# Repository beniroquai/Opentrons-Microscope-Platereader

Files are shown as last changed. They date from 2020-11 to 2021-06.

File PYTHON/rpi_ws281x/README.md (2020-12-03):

rpi_ws281x
==========

Userspace Raspberry Pi library for controlling WS281X LEDs.
This includes WS2812 and SK6812RGB RGB LEDs
Preliminary support is now included for SK6812RGBW LEDs (yes, RGB + W)
The LEDs can be controlled by either the PWM (2 independent channels)
or PCM controller (1 channel) or the SPI interface (1 channel).

### Bindings:

Language-specific bindings for rpi_ws281x are available in:

* Python - https://github.com/rpi-ws281x/rpi-ws281x-python
* Rust - https://github.com/rpi-ws281x/rpi-ws281x-rust
* Powershell - https://github.com/rpi-ws281x/rpi-ws281x-powershell
* Java - https://github.com/rpi-ws281x/rpi-ws281x-java
* CSharp - https://github.com/rpi-ws281x/rpi-ws281x-csharp
* Go - https://github.com/rpi-ws281x/rpi-ws281x-go

### Background:

The BCM2835 in the Raspberry Pi has both a PWM and a PCM module that
are well suited to driving individually controllable WS281X LEDs.
Using the DMA, PWM or PCM FIFO, and serial mode in the PWM, it's
possible to control almost any number of WS281X LEDs in a chain connected
to the appropriate output pin.
For SPI the Raspbian spidev driver is used (`/dev/spidev0.0`).
This library and test program set the clock rate to 3X the desired output
frequency and creates a bit pattern in RAM from an array of colors where
each bit is represented by 3 bits as follows.

    Bit 1 - 1 1 0
    Bit 0 - 1 0 0

### GPIO Usage:

The GPIOs that can be used are limited by the hardware of the Pi and will
vary based on the method used to drive them (PWM, PCM or SPI).
Beware that the GPIO numbers are not the same as the physical pin numbers
on the header.

PWM:
```
        PWM0, which can be set to use GPIOs 12, 18, 40, and 52.
        Only 12 (pin 32) and 18 (pin 12) are available on the B+/2B/3B

        PWM1 which can be set to use GPIOs 13, 19, 41, 45 and 53.
        Only 13 is available on the B+/2B/PiZero/3B, on pin 33
```

PCM:
```
        PCM_DOUT, which can be set to use GPIOs 21 and 31.
        Only 21 is available on the B+/2B/PiZero/3B, on pin 40.
```

SPI:
```
        SPI0-MOSI is available on GPIOs 10 and 38.
        Only GPIO 10 is available on all models.
        See also note for RPi 3 below.
```

### Power and voltage requirements

WS281X LEDs are generally driven at 5V. Depending on your actual
LED model and data line length you might be able to successfully drive
the data input with 3.3V. However in the general case you probably
want to use a level shifter to convert from the Raspberry Pi GPIO/PWM to 5V.

It is also possible to run the LEDs from a 3.3V - 3.6V power source, and
connect the GPIO directly at a cost of brightness, but this isn't
recommended.

The test program is designed to drive a 8x8 grid of LEDs e.g.from
Adafruit (http://www.adafruit.com/products/1487) or Pimoroni
(https://shop.pimoroni.com/products/unicorn-hat).
Please see the Adafruit and Pimoroni websites for more information.

Know what you're doing with the hardware and electricity.  I take no
reponsibility for damage, harm, or mistakes.

### Build:

#### Build with SCons:

- Install Scons (on raspbian, `apt-get install scons`).
- Make sure to adjust the parameters in main.c to suit your hardware.
  - Signal rate (400kHz to 800kHz).  Default 800kHz.
  - ledstring.invert=1 if using a inverting level shifter.
  - Width and height of LED matrix (height=1 for LED string).
- Type `scons` from inside the source directory.

#### Build and install with CMake:

- Install CMake
- Configure your build:

  For example:
  ```
  mkdir build
  cd build
  cmake -D BUILD_SHARED=OFF -D BUILD_TEST=ON ..
  ```
  See also for available options in `CMakeLists.txt`.
- Type `cmake --build .` to build
- To install built binaries and headers into your system type:
  ```
  sudo make install
  ```

### Running:

- Type `sudo ./test` (default uses PWM channel 0).
- That's it.  You should see a moving rainbow scroll across the
  display.
- More options are available, `./test -h` should show them:
```
./test version 1.1.0
Usage: ./test
-h (--help)    - this information
-s (--strip)   - strip type - rgb, grb, gbr, rgbw
-x (--width)   - matrix width (default 8)
-y (--height)  - matrix height (default 8)
-d (--dma)     - dma channel to use (default 10)
-g (--gpio)    - GPIO to use
                 If omitted, default is 18 (PWM0)
-i (--invert)  - invert pin output (pulse LOW)
-c (--clear)   - clear matrix on exit.
-v (--version) - version information
```

### Important warning about DMA channels

You must make sure that the DMA channel you choose to use for the LEDs is not [already in use](https://www.raspberrypi.org/forums/viewtopic.php?p=609380#p609380) by the operating system.

For example, **using DMA channel 5 [will cause](https://github.com/jgarff/rpi_ws281x/issues/224) filesystem corruption** on the Raspberry Pi 3 Model B.

The default DMA channel (10) should be safe for the Raspberry Pi 3 Model B, but this may change in future software releases.

### Limitations:

#### PWM

Since this library and the onboard Raspberry Pi audio
both use the PWM, they cannot be used together.  You will need to
blacklist the Broadcom audio kernel module by creating a file
`/etc/modprobe.d/snd-blacklist.conf` with

    blacklist snd_bcm2835

If the audio device is still loading after blacklisting, you may also
need to comment it out in the /etc/modules file.

On headless systems you may also need to force audio through hdmi
Edit config.txt and add:

    hdmi_force_hotplug=1
    hdmi_force_edid_audio=1

A reboot is required for this change to take effect

Some distributions use audio by default, even if nothing is being played.
If audio is needed, you can use a USB audio device instead.

#### PCM

When using PCM you cannot use digital audio devices which use I2S since I2S
uses the PCM hardware, but you can use analog audio.

#### SPI

When using SPI the led string is the only device which can be connected to
the SPI bus. Both digital (I2S/PCM) and analog (PWM) audio can be used.

Many distributions have a maximum SPI transfer of 4096 bytes. This can be
changed in `/boot/cmdline.txt` by appending
```
    spidev.bufsiz=32768
```

On an RPi 3 you have to change the GPU core frequency to 250 MHz, otherwise
the SPI clock has the wrong frequency.

Do this by adding the following line to /boot/config.txt and reboot:

```
    core_freq=250
```

On an RPi 4 you must set a fixed frequency to avoid the idle CPU scaling changing the SPI frequency and breaking the ws281x timings:

Do this by adding the following lines to /boot/config.txt and reboot:

```
    core_freq=500
    core_freq_min=500
```

SPI requires you to be in the `gpio` group if you wish to control your LEDs
without root.

### Comparison PWM/PCM/SPI

Both PWM and PCM use DMA transfer to output the control signal for the LEDs.
The max size of a DMA transfer is 65536 bytes. Since each LED needs 12 bytes
(4 colors, 8 symbols per color, 3 bits per symbol) this means you can
control approximately 5400 LEDs for a single strand in PCM and 2700 LEDs per string
for PWM (Only PWM can control 2 independent strings simultaneously)
SPI uses the SPI device driver in the kernel. For transfers larger than
96 bytes the kernel driver also uses DMA.
Of course there are practical limits on power and signal quality. These will
be more constraining in practice than the theoretical limits above.

When controlling a LED string of 240 LEDs the CPU load on the original Pi 2 (BCM2836) are:
  PWM  5%
  PCM  5%
  SPI  1%

### Usage:

The API is very simple.  Make sure to create and initialize the `ws2811_t`
structure as seen in [`main.c`](main.c).  From there it can be initialized
by calling `ws2811_init()`.  LEDs are changed by modifying the color in
the `.led[index]` array and calling `ws2811_render()`.
The rest is handled by the library, which either creates the DMA memory and
starts the DMA for PWM and PCM or prepares the SPI transfer buffer and sends
it out on the MISO pin.

Make sure to hook a signal handler for SIGKILL to do cleanup.  From the
handler make sure to call `ws2811_fini()`.  It'll make sure that the DMA
is finished before program execution stops and cleans up after itself.

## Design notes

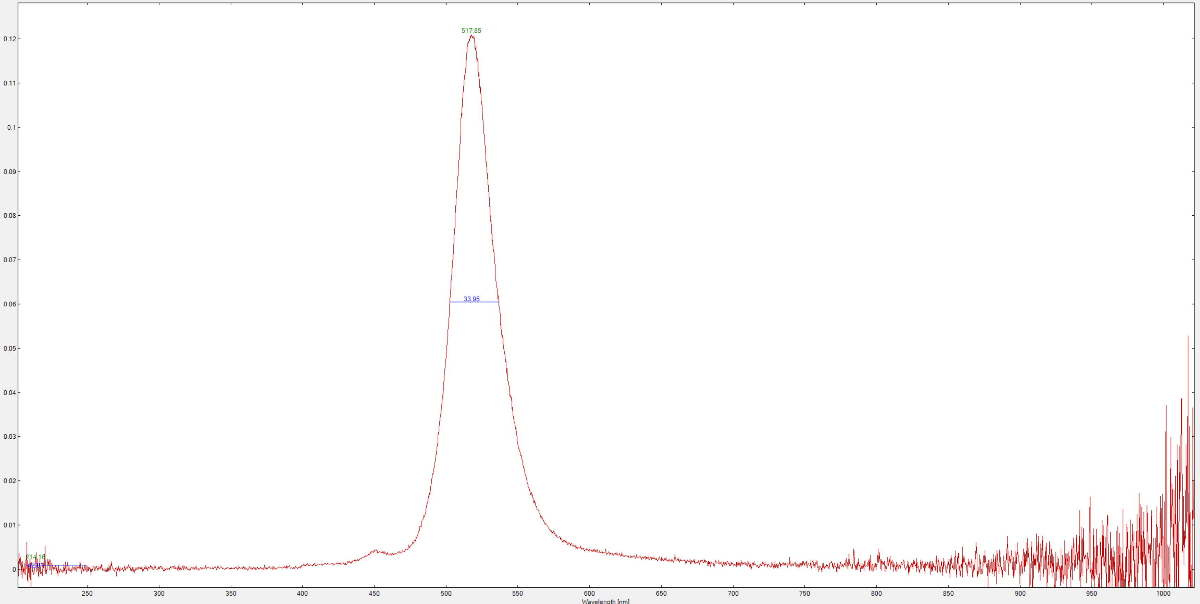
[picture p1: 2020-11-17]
IMAGES/Spectrometer_Neopixel_ring_onlyGreen.PNG

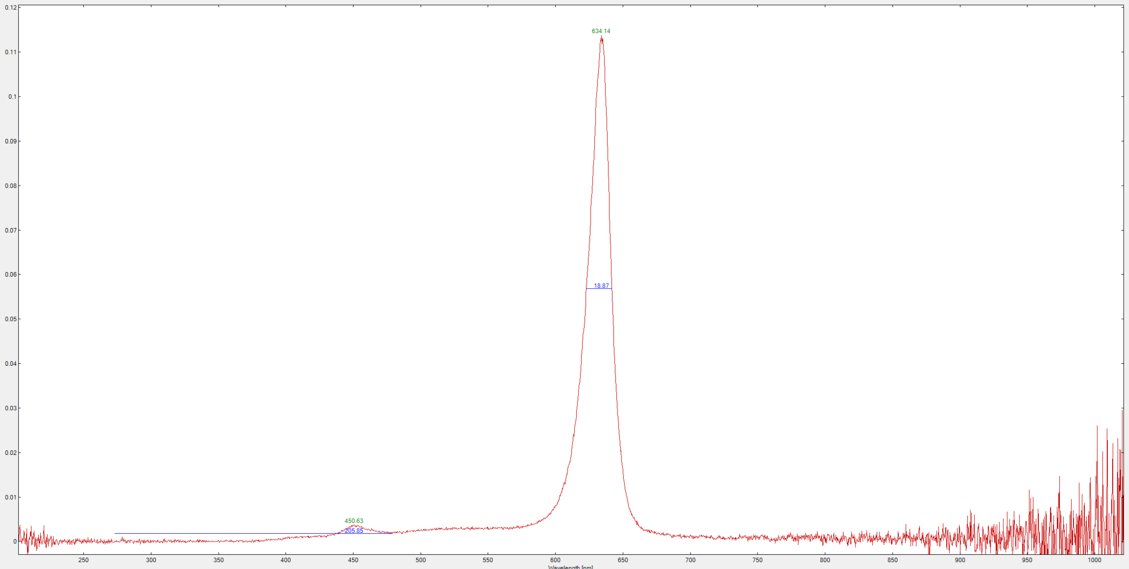
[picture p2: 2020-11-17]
IMAGES/Spectrometer_Neopixel_ring_onlyRed.PNG

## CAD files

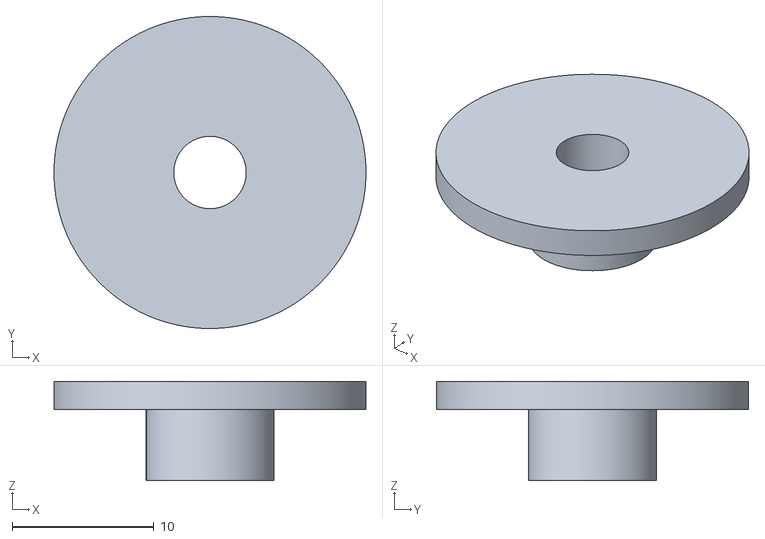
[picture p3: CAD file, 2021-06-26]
INVENTOR/13_Fluorescence_Arm_LEDholder.stl
22.0 x 22.0 x 7.00

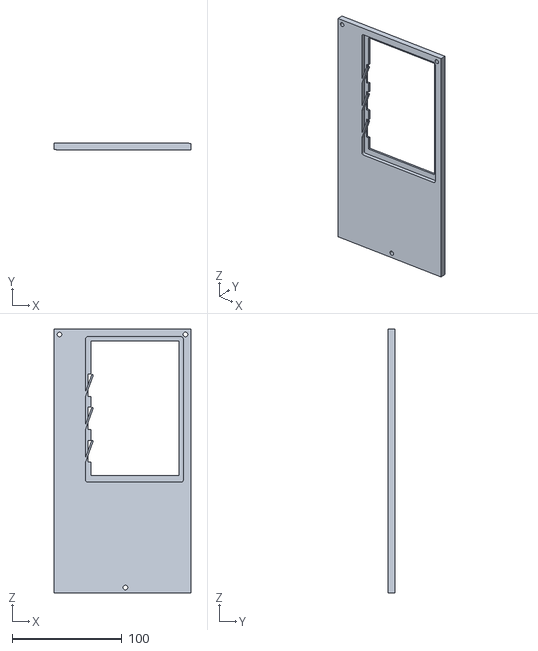
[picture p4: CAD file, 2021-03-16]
STL/Opentronscope_04_OPENTRONS_Microscope_wellplate_base.stl
125.0 x 6.07 x 241.0

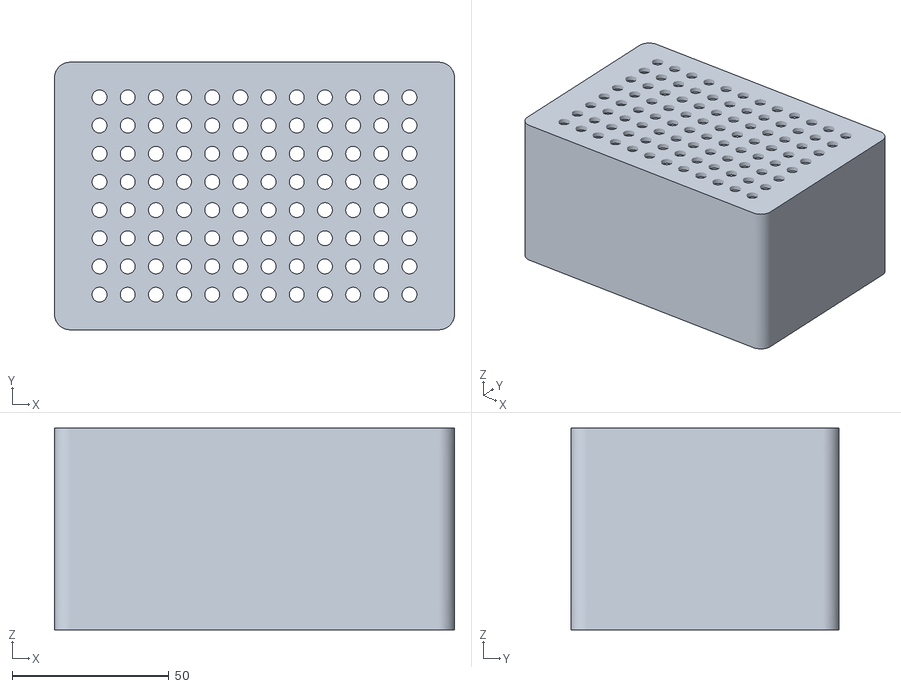
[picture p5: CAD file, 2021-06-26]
INVENTOR/00_Rack_Eppendorf_96_200mul_tips.stl
127.8 x 85.5 x 64.5

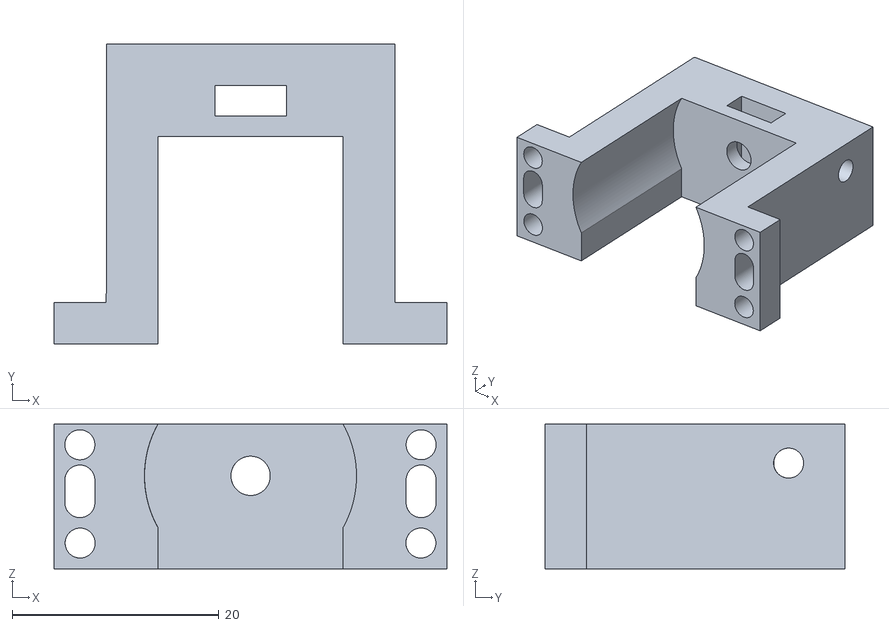
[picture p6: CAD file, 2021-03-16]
STL/Opentronscope_opentrons_Gearbox.stl
38.0 x 29.0 x 14.0

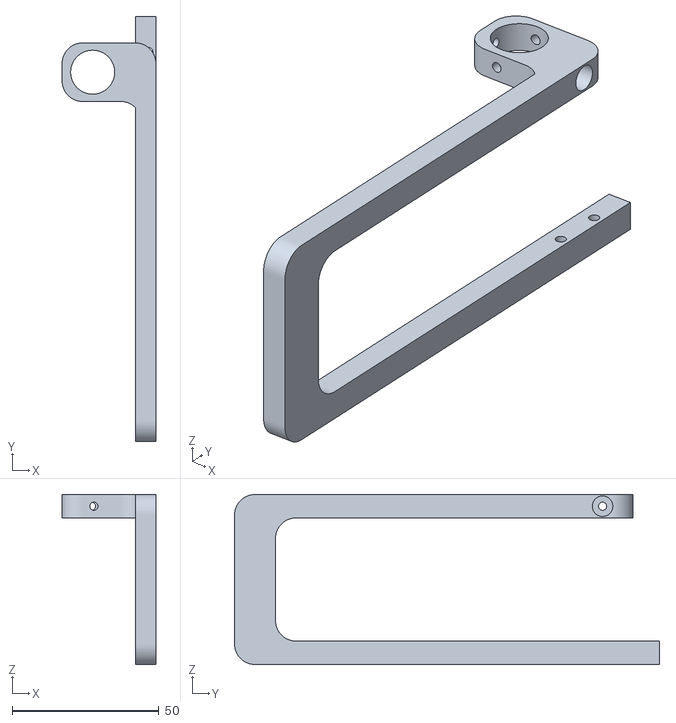
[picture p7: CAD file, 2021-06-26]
INVENTOR/06_Fluorescence_Arm.stl
32.0 x 145.0 x 58.0

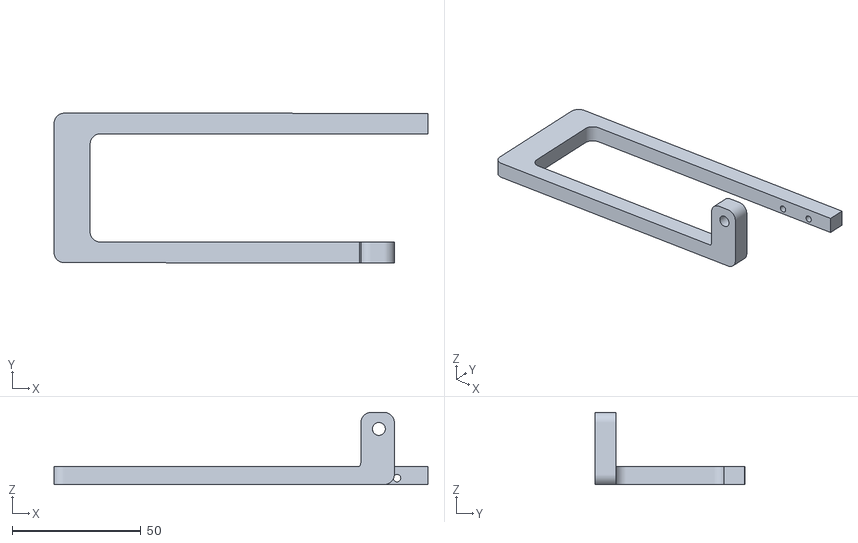
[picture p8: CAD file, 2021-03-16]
STL/Opentronscope_06_Fluorescence_Arm.stl
145.0 x 58.1 x 28.0

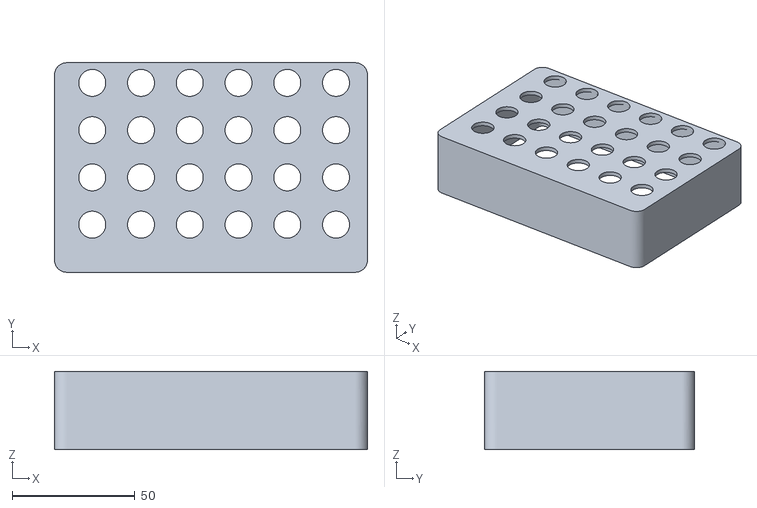
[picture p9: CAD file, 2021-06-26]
INVENTOR/00_Rack_Eppendorf_Tubes.stl
127.7 x 85.5 x 32.0

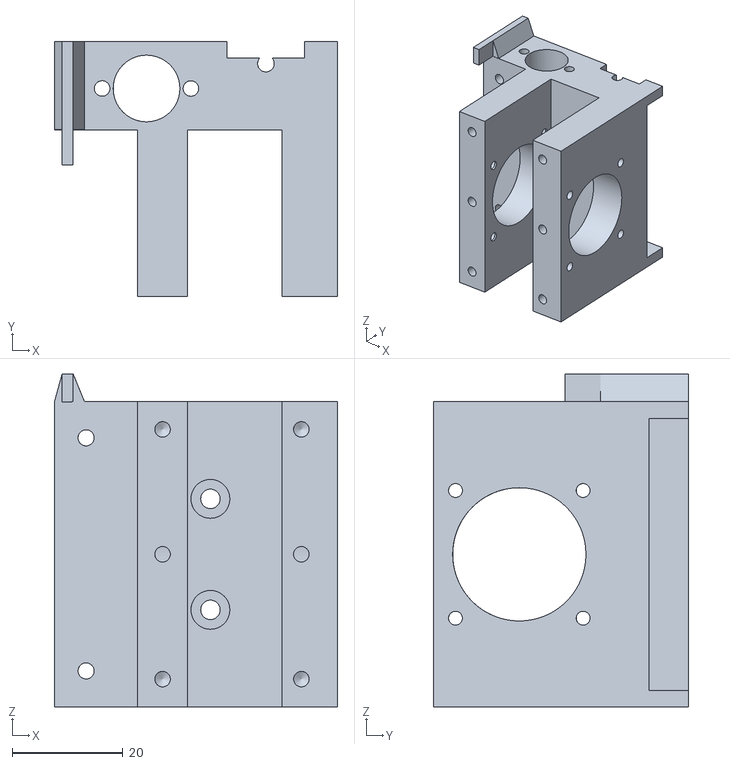
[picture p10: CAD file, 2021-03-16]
STL/Opentronscope_01_Slide_camera_y_v0.stl
51.0 x 46.0 x 60.0

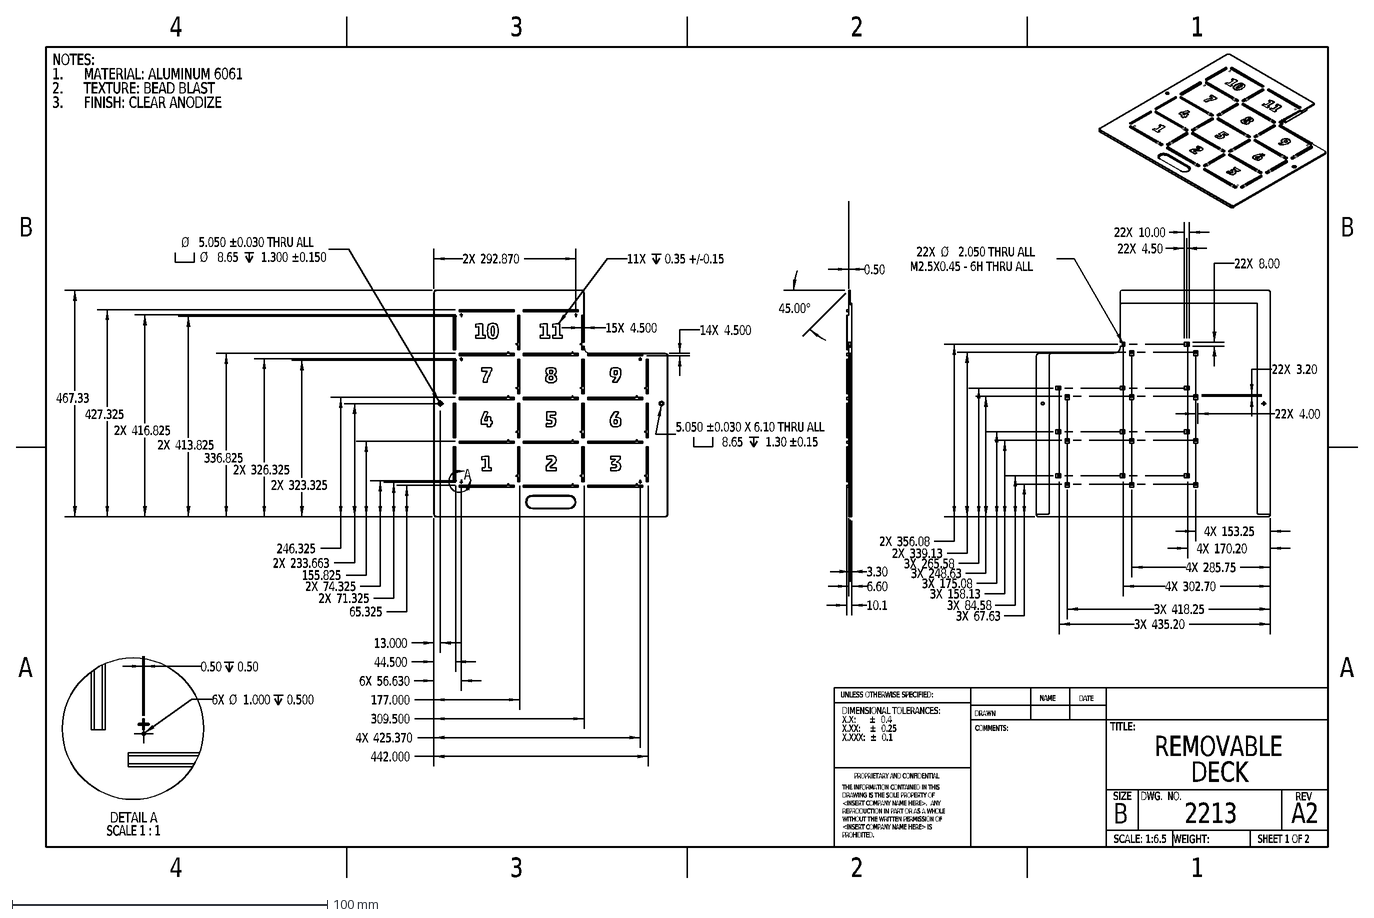
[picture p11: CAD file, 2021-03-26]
INVENTOR/CNC_DECK_RevA2.DXF
NOTES:
MATERIAL: ALUMINUM 6061
1.
TEXTURE: BEAD BLAST
2.
FINISH: CLEAR ANODIZE
3.
REMOVABLE
DECK
A2
2213
SHEET 1 OF 2
UNLESS OTHERWISE SPECIFIED:
SCALE: 1:6.5
WEIGHT:
REV
DWG. NO.
B
SIZE
TITLE:
NAME
DATE
COMMENTS:
DRAWN
PROPRIETARY AND CONFIDENTIAL
THE INFORMATION CONTAINED IN THIS
DRAWING IS THE SOLE PROPERTY OF
<INSERT COMPANY NAME HERE>. ANY
REPRODUCTION IN PART OR AS A WHOLE
WITHOUT THE WRITTEN PERMISSION OF
<INSERT COMPANY NAME HERE> IS
PROHIBITED.
DIMENSIONAL TOLERANCES:
X.X:
±
0.4
X.XX:
0.25
X.XXX:
0.1
A
4
3
2
1
2X
233.663
71.325
65.325
155.825
246.325
336.825
427.325
326.325
416.825
467.33
13.000
44.500
309.500
442.000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

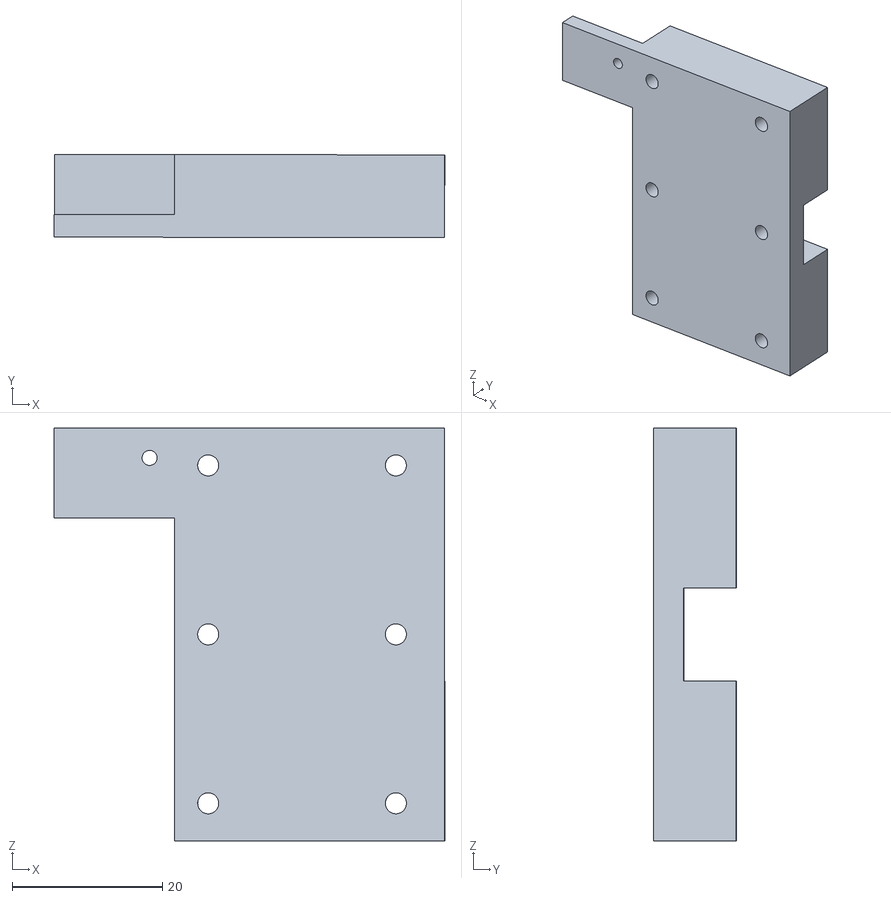
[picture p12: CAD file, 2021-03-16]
STL/Opentronscope_04_Mount_Rail_Fastener.stl
52.0 x 11.0 x 55.0

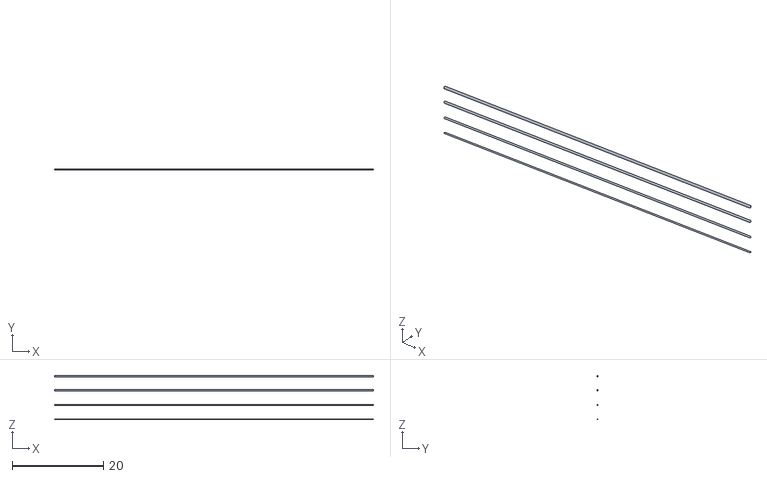
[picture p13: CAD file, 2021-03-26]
INVENTOR/Part1.stl
70.0 x 0.3 x 9.70

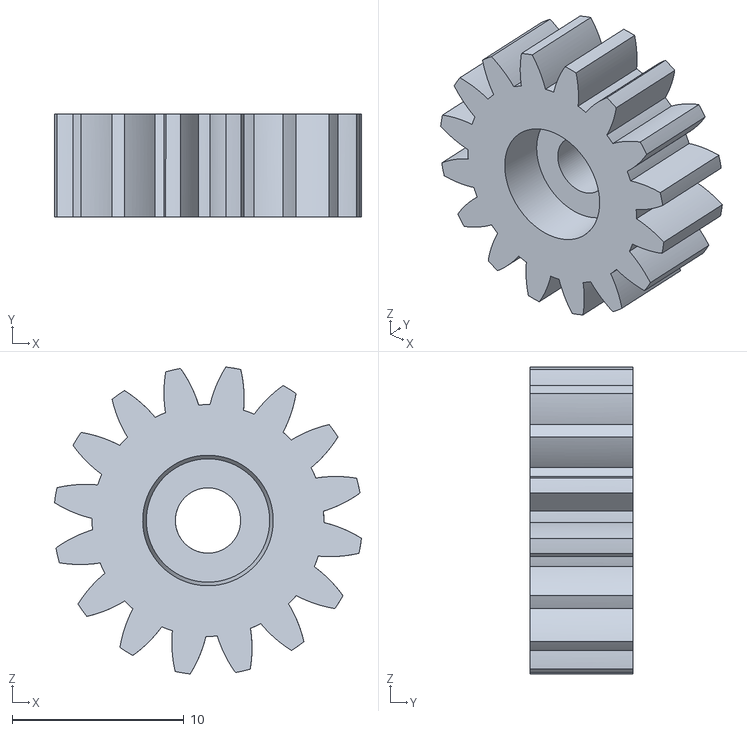
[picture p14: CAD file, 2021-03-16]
STL/Opentronscope_opentrons_gear2.stl
17.9 x 6.01 x 17.9

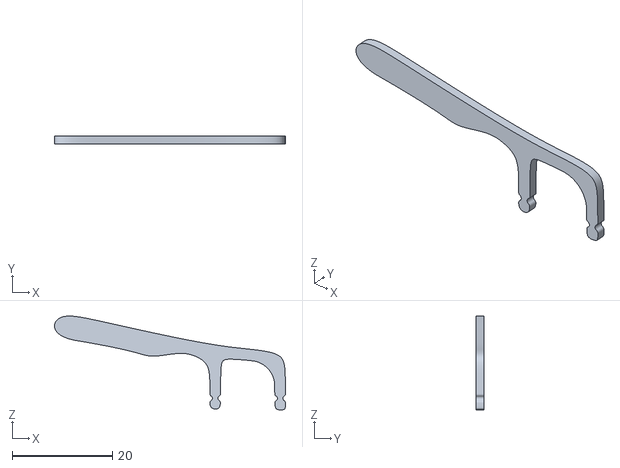
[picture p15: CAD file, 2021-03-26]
INVENTOR/toothpick.stl
46.1 x 1.50 x 18.7

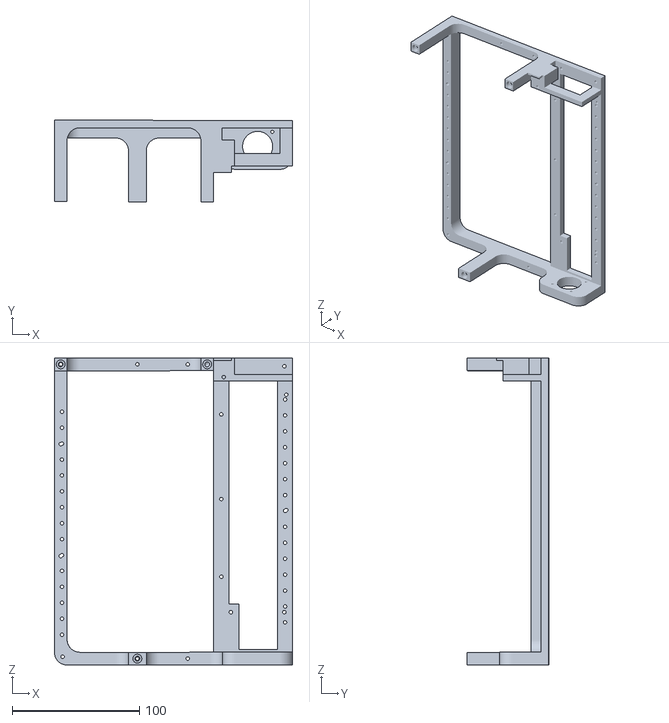
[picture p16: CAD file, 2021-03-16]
STL/Opentronscope_02_Opentrons_Microscope_Base_v0.stl
187.1 x 64.1 x 241.0

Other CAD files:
INVENTOR/09_Lid_Electronics.stl
STL/Opentronscope_01_Slide_camera_v1.stl
INVENTOR/09_Opentrons_Microscope_Baseplate.stl
STL/Opentronscope_01_Slide_camera_flexure_v1.stl
INVENTOR/00_Beampath_Autofocus _2.ipt
INVENTOR/00_COMAR_Mirror_10mm.ipt
INVENTOR/00_ESP32_Camera_only.ipt
INVENTOR/00_Endstop.ipt
INVENTOR/00_IGUS_Drylin_RJ4JP-01-06.ipt
INVENTOR/00_IR_Laserdiode.ipt
INVENTOR/00_LED_neopixel_single.ipt
INVENTOR/00_MGN12 LINEAR GUIDE RAIL, CONFIGURABLE.ipt
INVENTOR/00_MGN12C, LINEAR GUIDE BLOCK.ipt
INVENTOR/00_MGN12H, LINEAR GUIDE BLOCK.ipt
INVENTOR/00_NEMA11.iam
INVENTOR/00_Rack_Eppendorf_96_200mul_tips.ipt
INVENTOR/00_Rack_Eppendorf_Tubes.ipt
INVENTOR/00_RasPi_Camera.ipt
INVENTOR/00_Raspberry_Pi_3.iam
INVENTOR/00_Thorlabs_Rod_200mm.ipt
INVENTOR/00_coverslip.ipt
INVENTOR/00_endstop_optical.ipt
INVENTOR/00_endstop_optical.stp
INVENTOR/00_lens_10mm.ipt
INVENTOR/00_objectivelens_10x.ipt
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

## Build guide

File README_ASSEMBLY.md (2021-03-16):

# Assemble the XY-stage 

These are more-less all components you would need for the XY-stage to operate. The Z-focus assembly is explained below

### All ingredients

<p align="left">
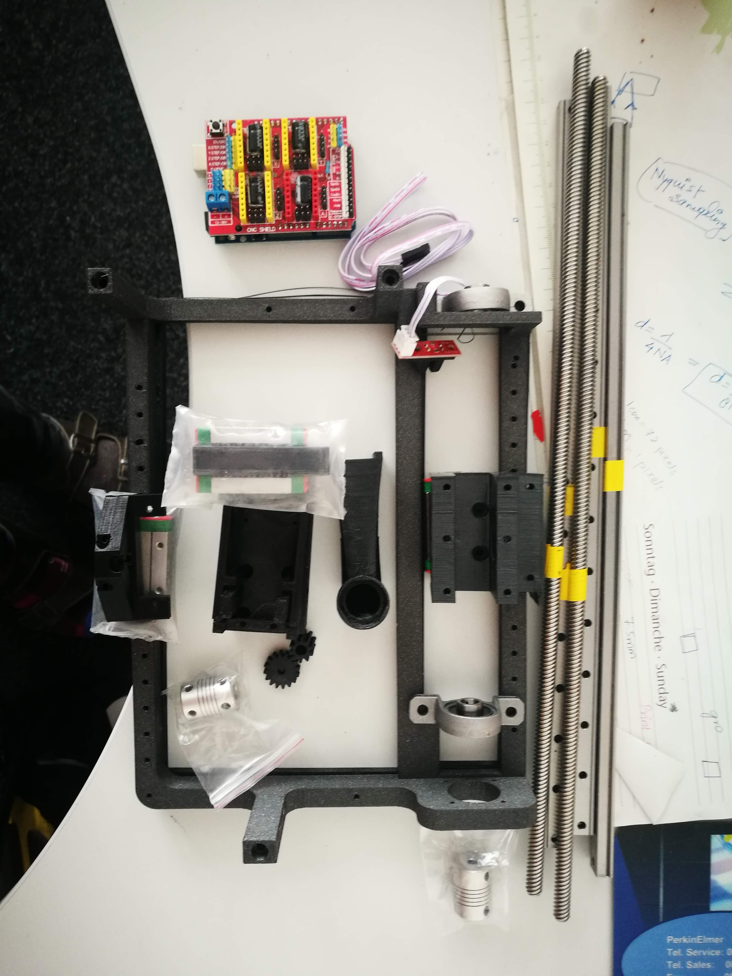
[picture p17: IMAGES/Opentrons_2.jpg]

</p>

### Prepare the metal parts / slides

Cut! 

<p align="left">
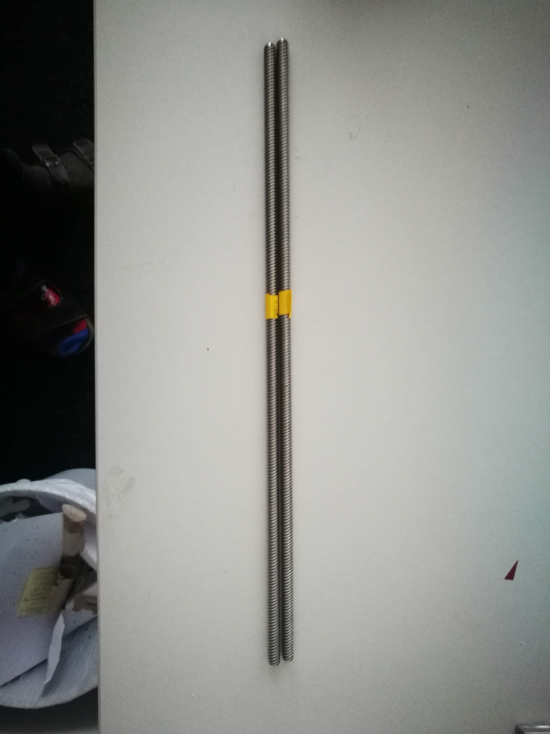
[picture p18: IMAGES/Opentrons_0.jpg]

</p>

<p align="left">
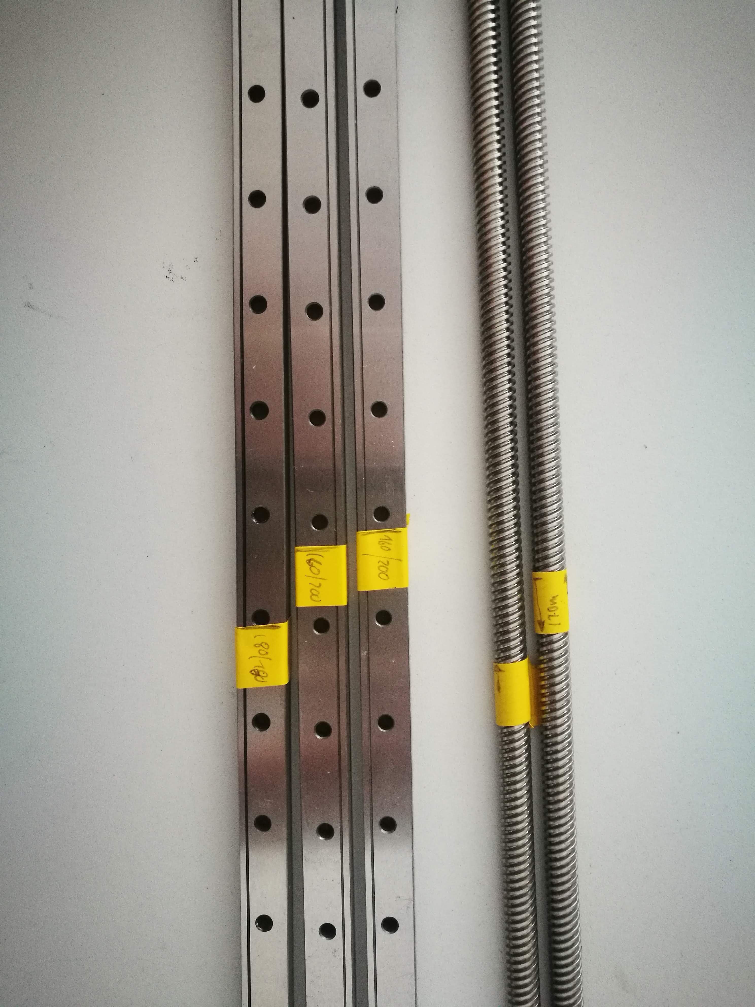
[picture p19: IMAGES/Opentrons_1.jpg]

</p>

### Assembling the optics module

<p align="left">
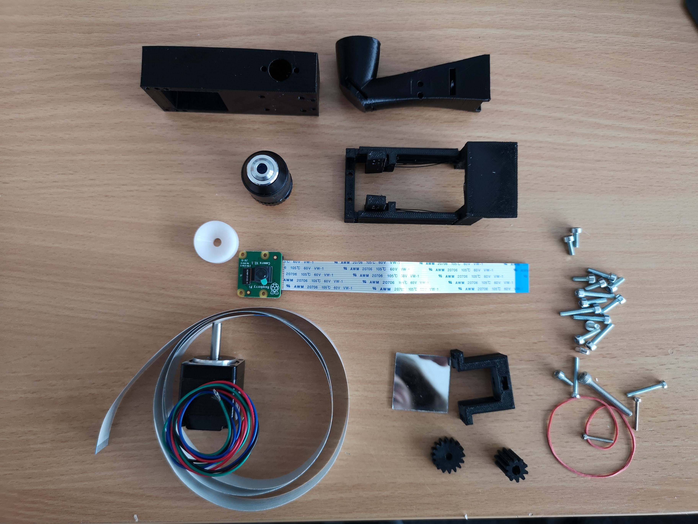
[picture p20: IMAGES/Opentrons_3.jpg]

</p>

<p align="left">
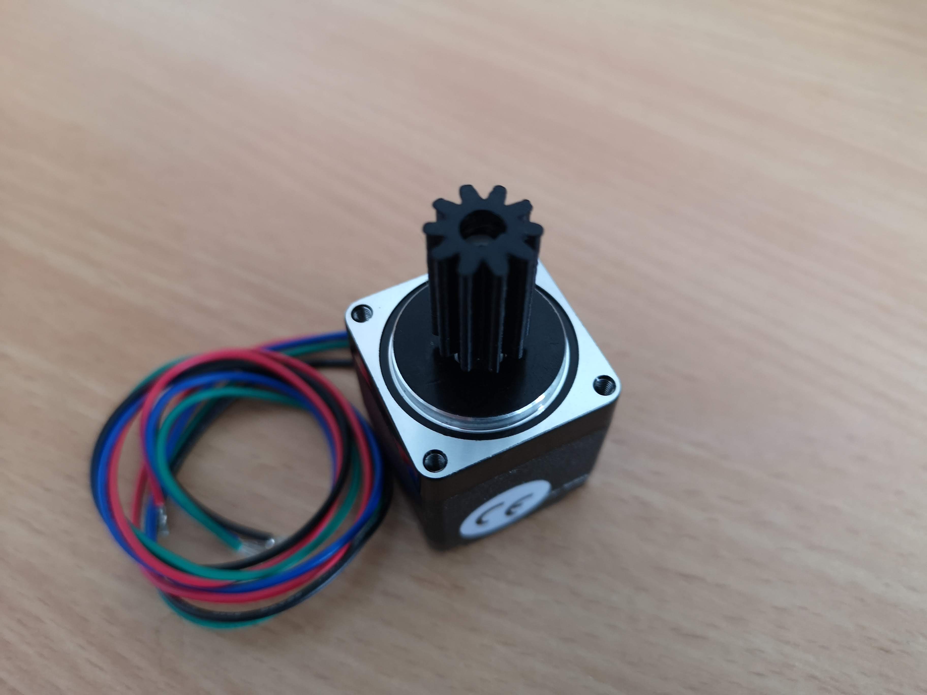
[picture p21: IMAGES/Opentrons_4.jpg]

</p>

<p align="left">
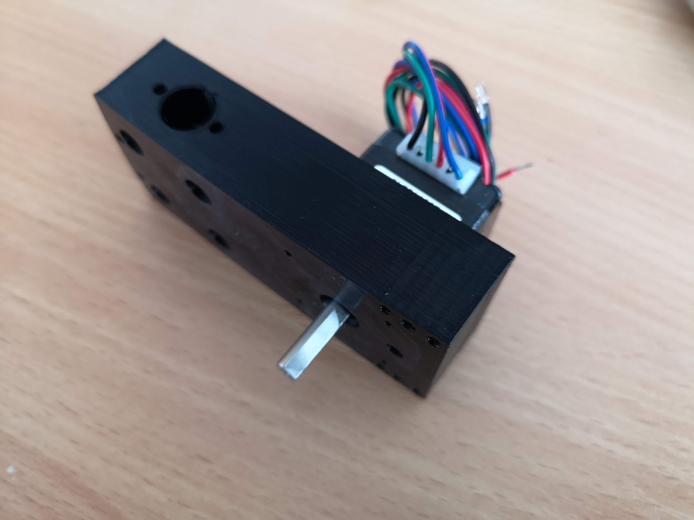
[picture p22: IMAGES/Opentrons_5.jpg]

</p>

<p align="left">
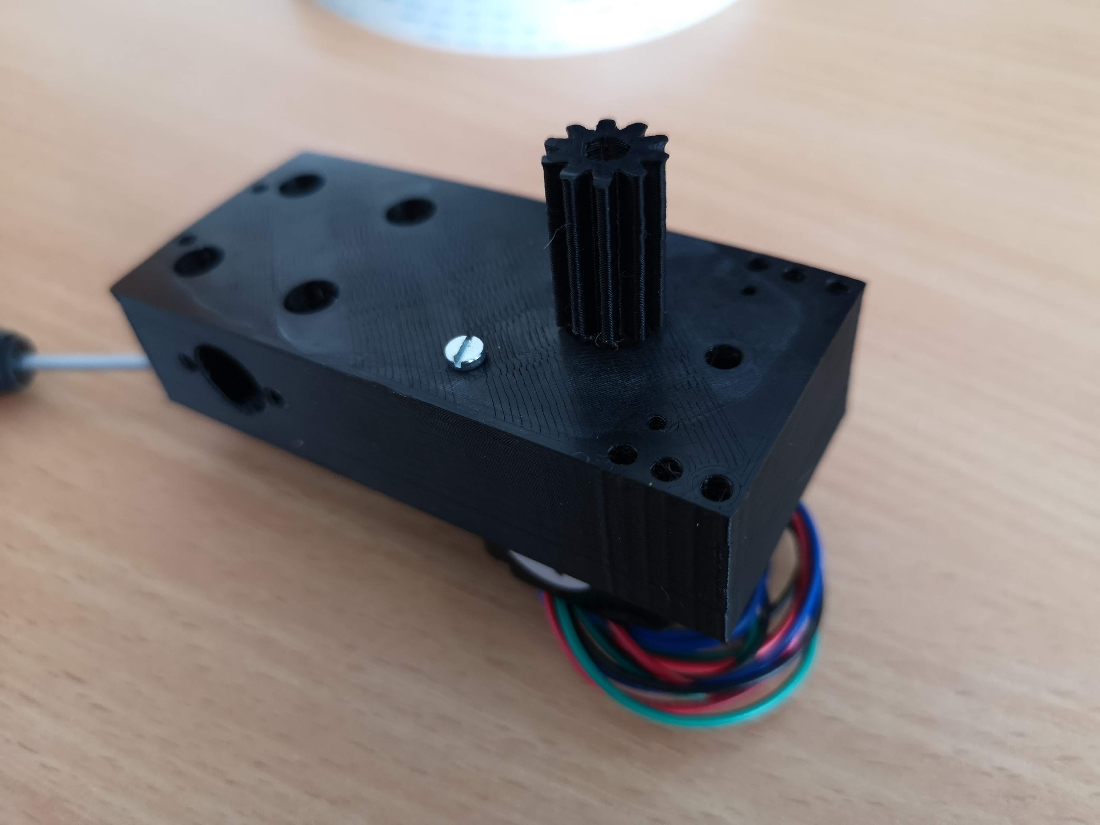
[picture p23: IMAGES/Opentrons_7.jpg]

</p>

<p align="left">
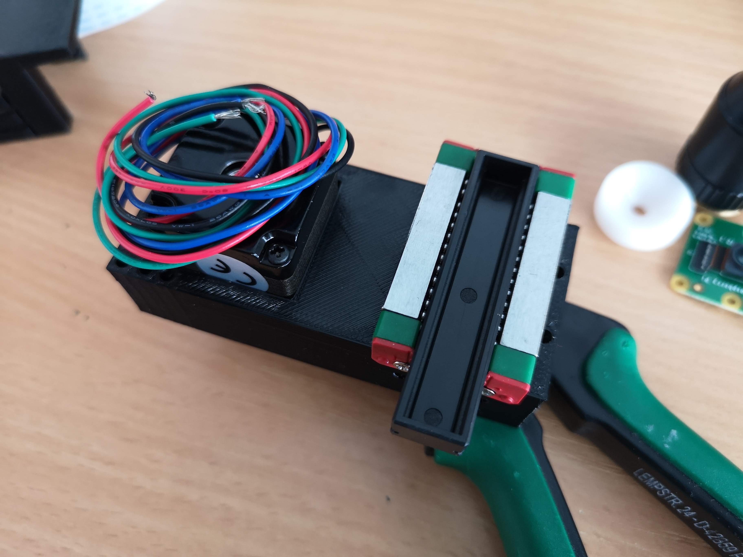
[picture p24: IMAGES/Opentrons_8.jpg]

</p>

<p align="left">
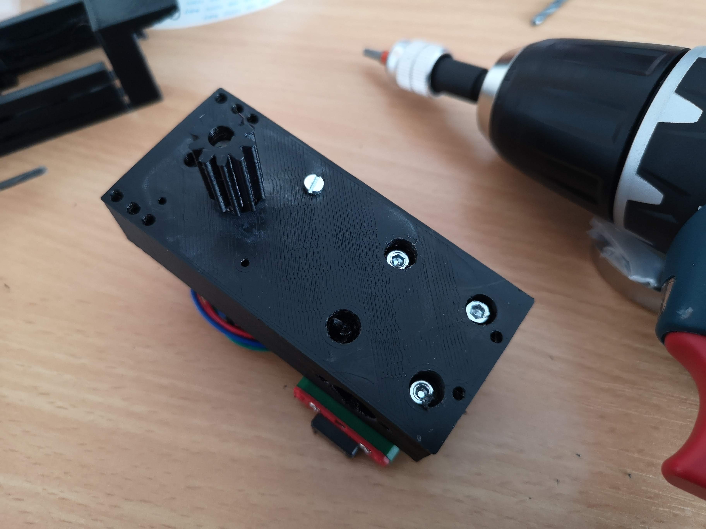
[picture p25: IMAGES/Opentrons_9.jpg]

</p>

<p align="left">
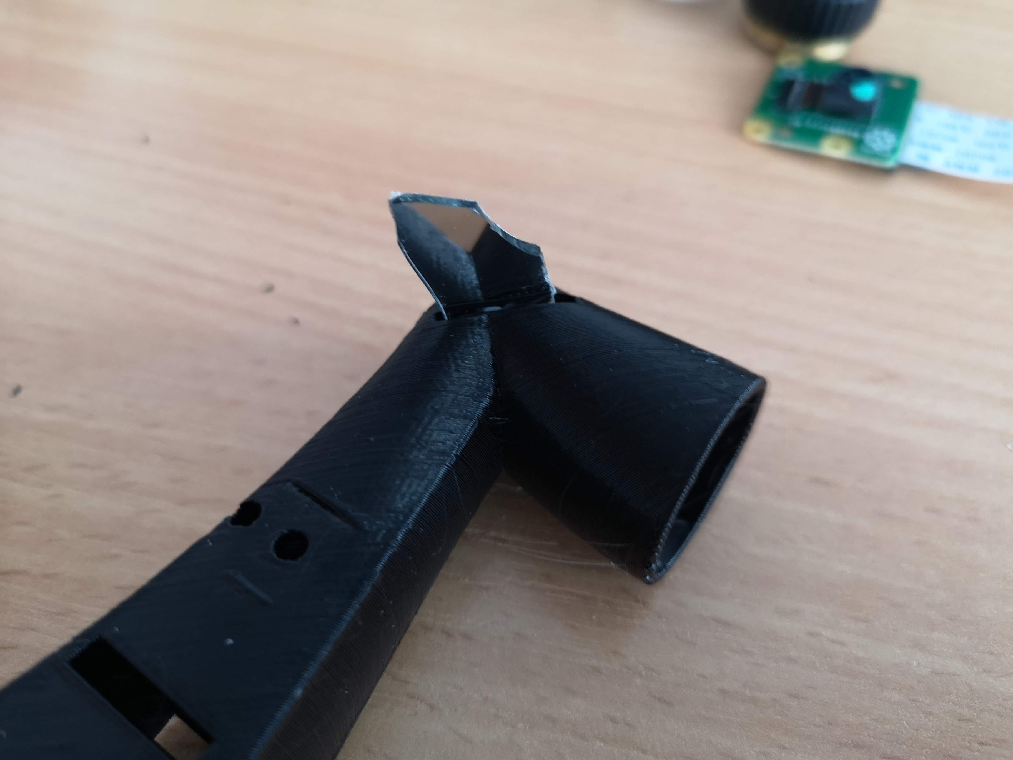
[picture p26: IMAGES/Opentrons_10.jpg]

</p>

<p align="left">
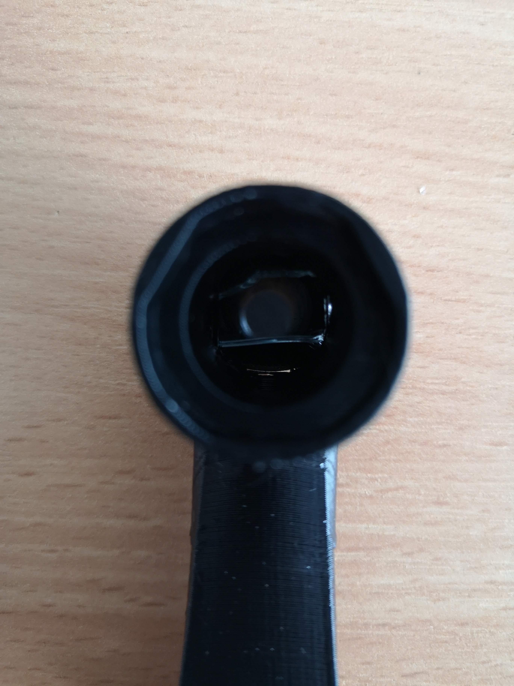
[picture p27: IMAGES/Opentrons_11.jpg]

</p>

<p align="left">
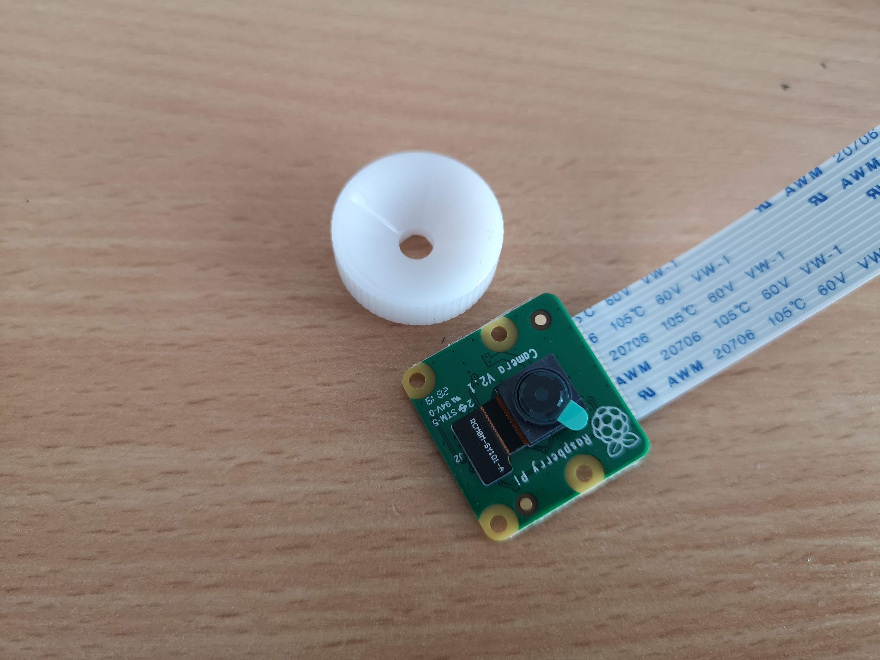
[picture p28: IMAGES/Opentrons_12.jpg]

</p>

<p align="left">
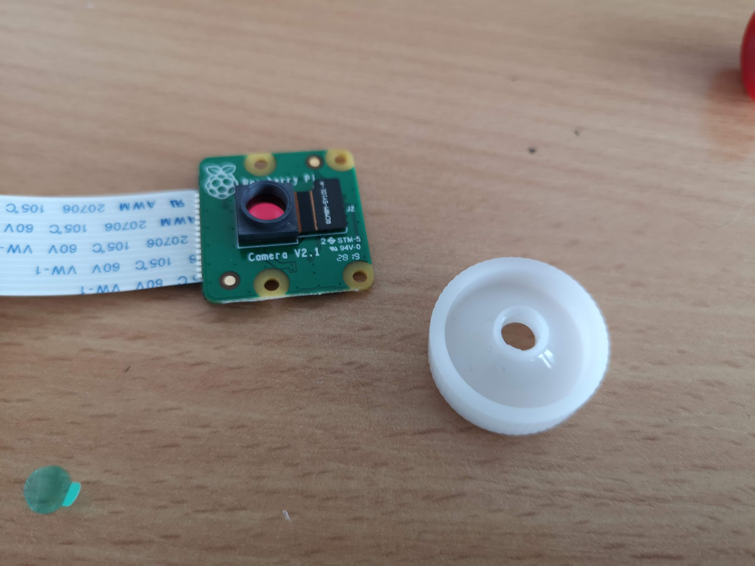
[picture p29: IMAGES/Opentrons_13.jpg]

</p>

<p align="left">
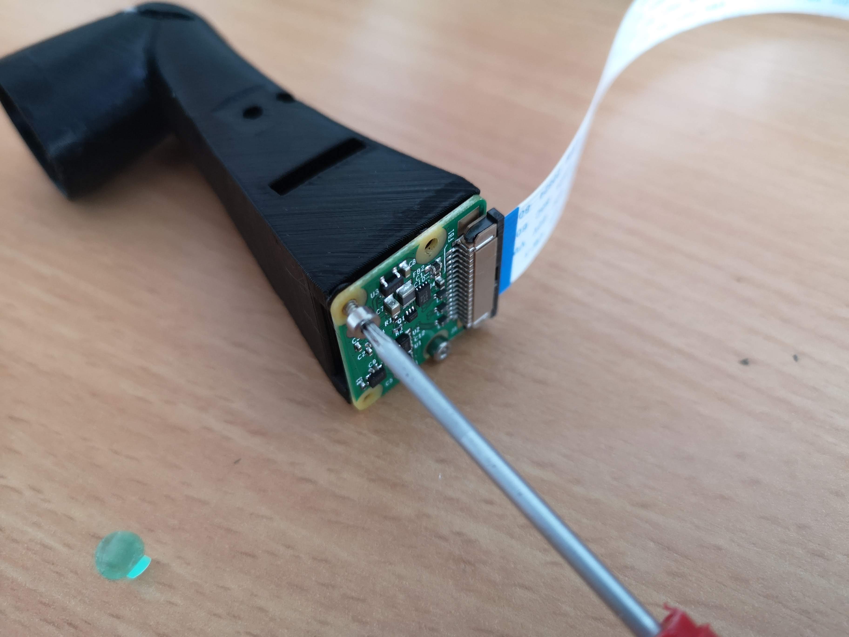
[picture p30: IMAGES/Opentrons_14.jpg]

</p>

<p align="left">
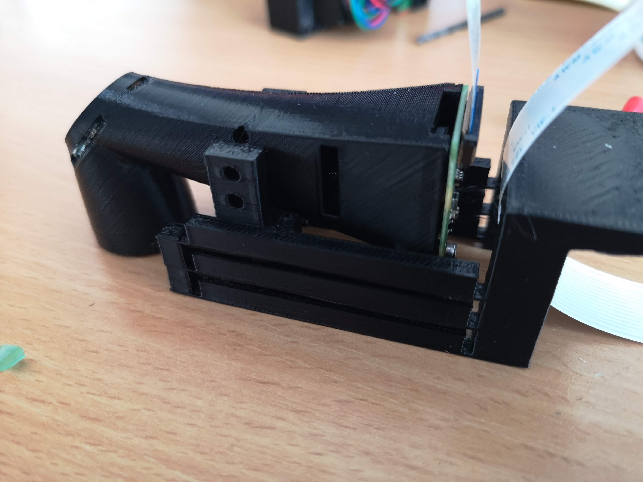
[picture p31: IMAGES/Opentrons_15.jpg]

</p>

<p align="left">
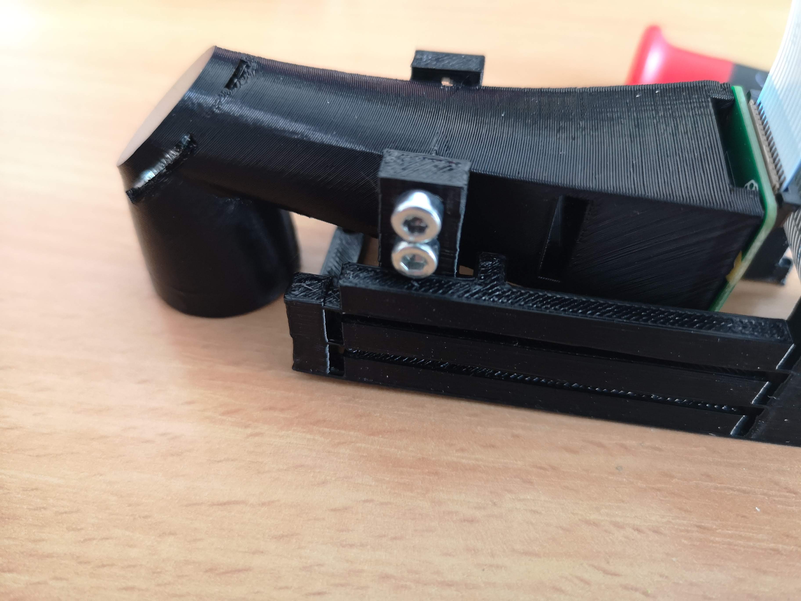
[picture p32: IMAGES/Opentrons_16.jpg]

</p>

<p align="left">
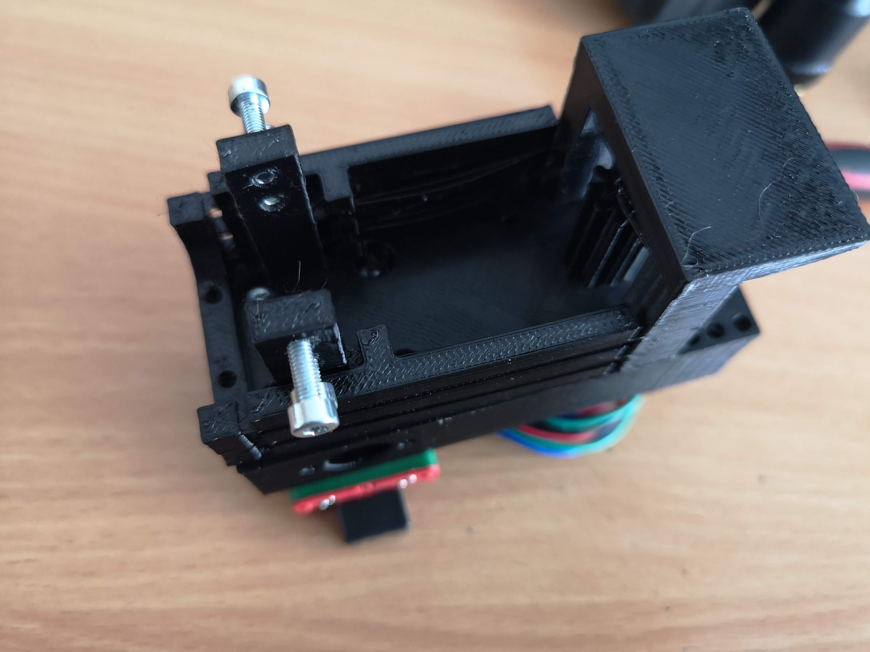
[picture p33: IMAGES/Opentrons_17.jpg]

</p>

<p align="left">
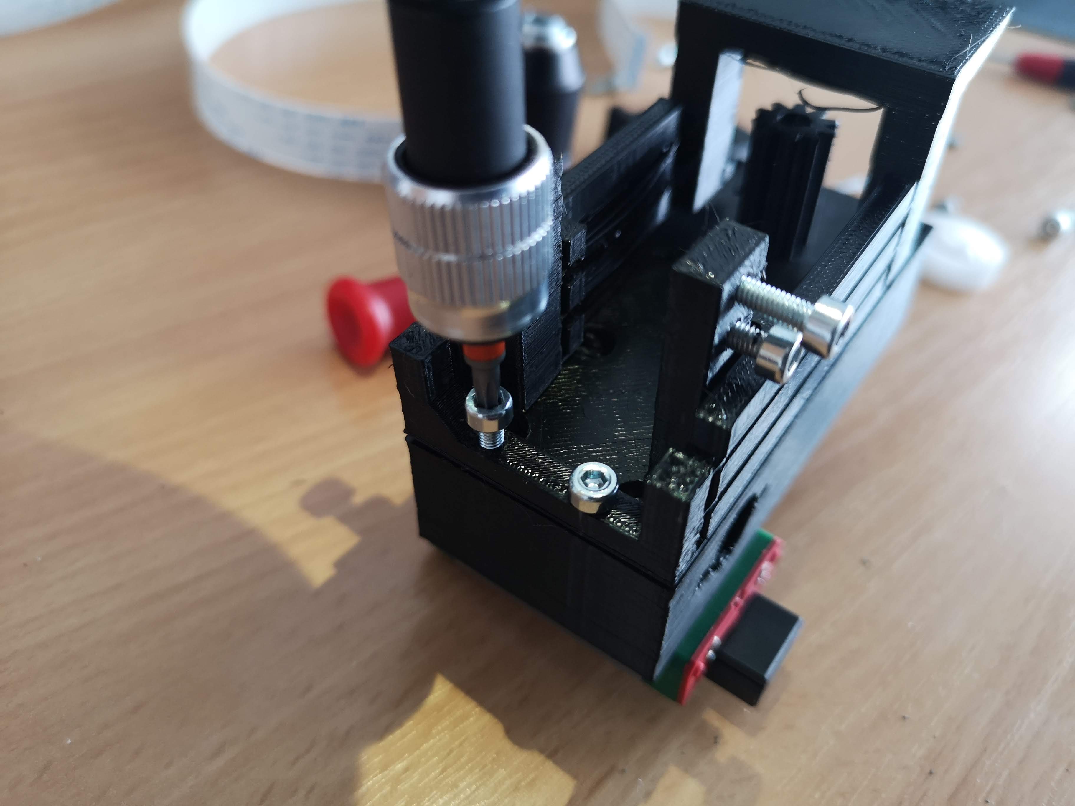
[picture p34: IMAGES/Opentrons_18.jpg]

</p>

<p align="left">
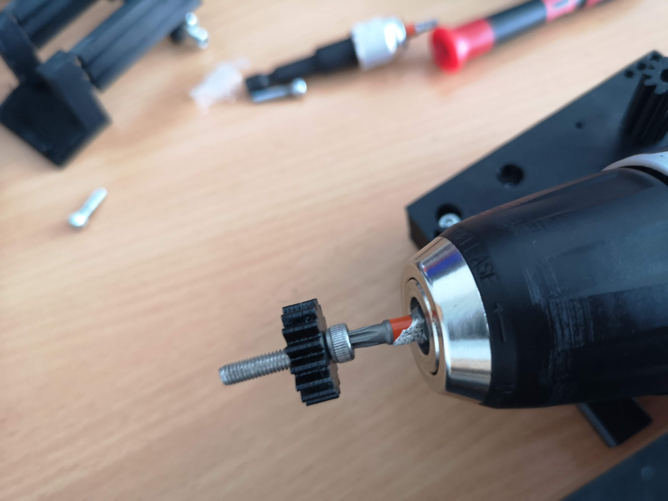
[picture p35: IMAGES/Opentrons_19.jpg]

</p>

<p align="left">
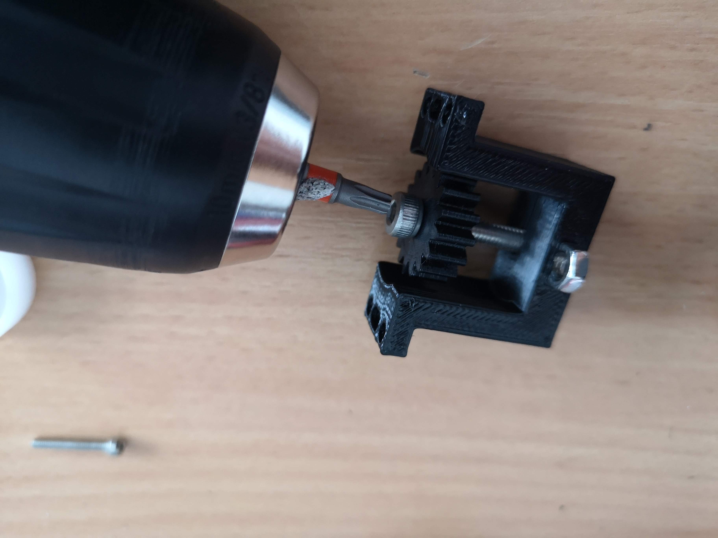
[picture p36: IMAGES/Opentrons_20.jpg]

</p>

<p align="left">

</p>

<p align="left">
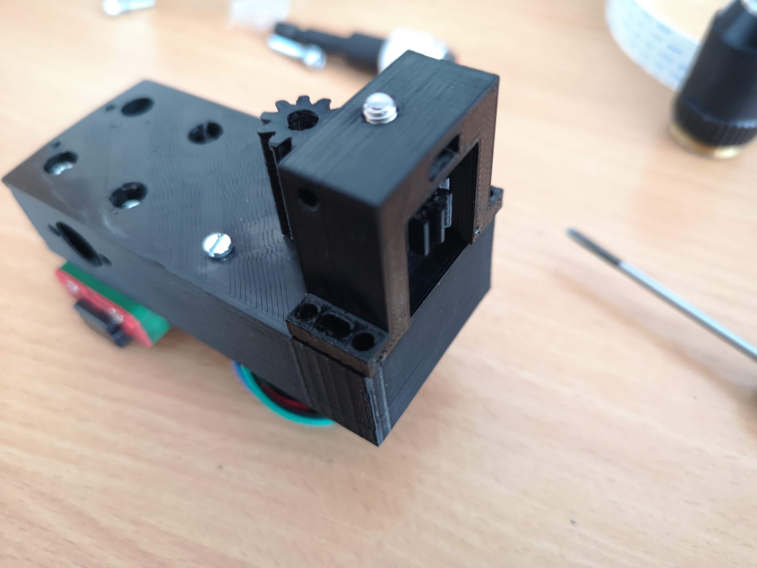
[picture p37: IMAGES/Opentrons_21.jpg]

</p>

<p align="left">
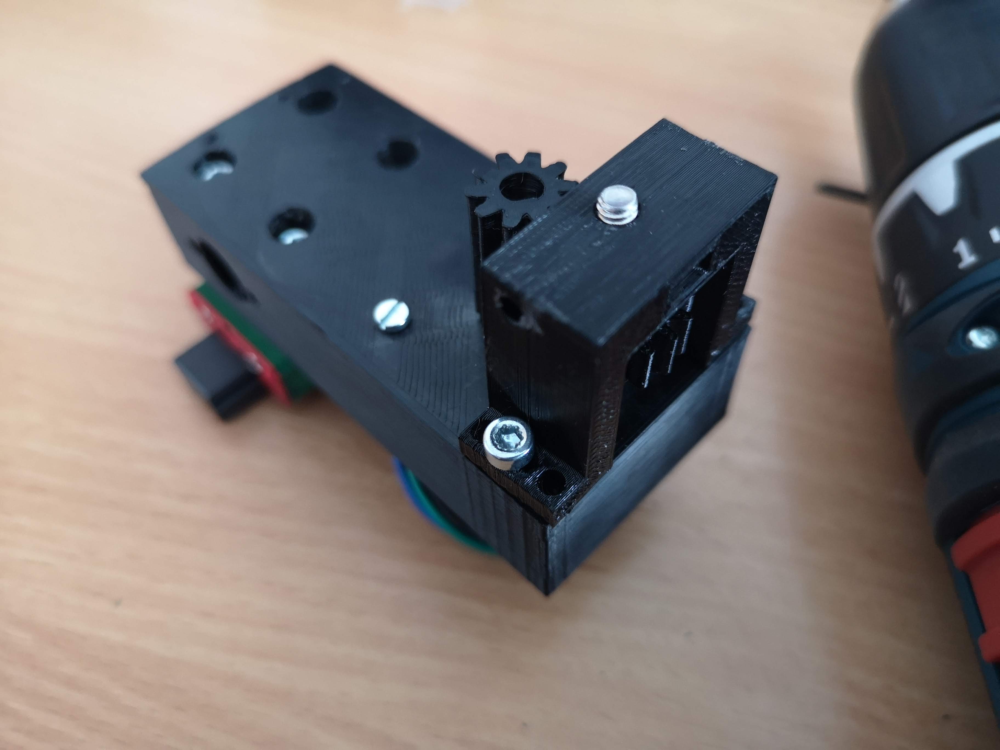
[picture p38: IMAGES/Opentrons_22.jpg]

</p>

<p align="left">
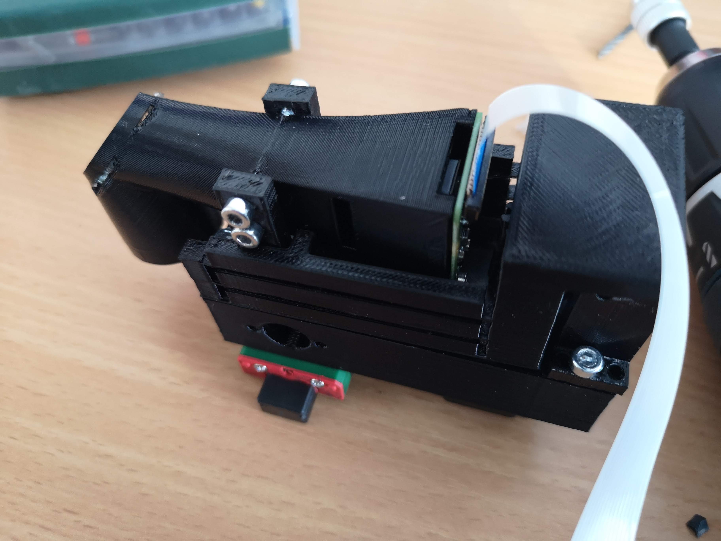
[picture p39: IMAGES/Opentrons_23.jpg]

</p>

<p align="left">
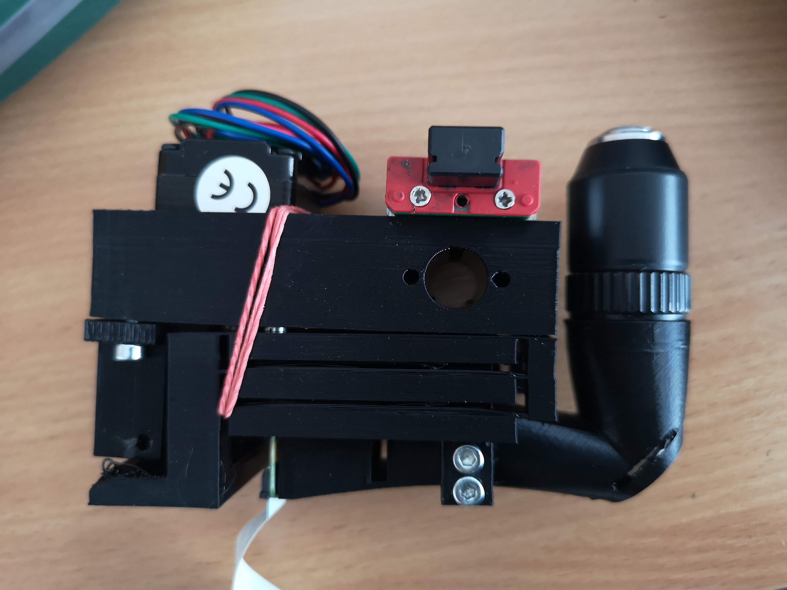
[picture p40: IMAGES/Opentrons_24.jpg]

</p>

<p align="left">
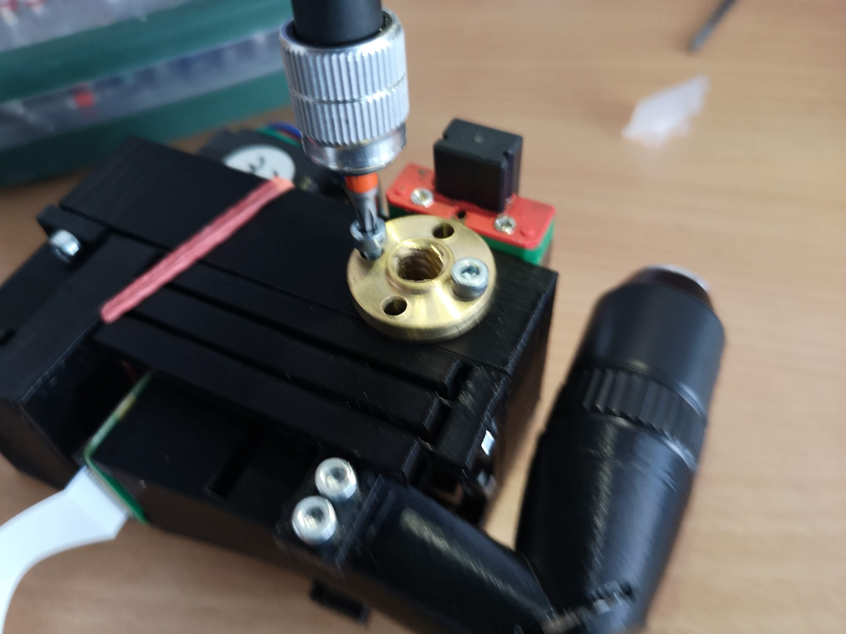
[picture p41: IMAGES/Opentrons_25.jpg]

</p>

<p align="left">
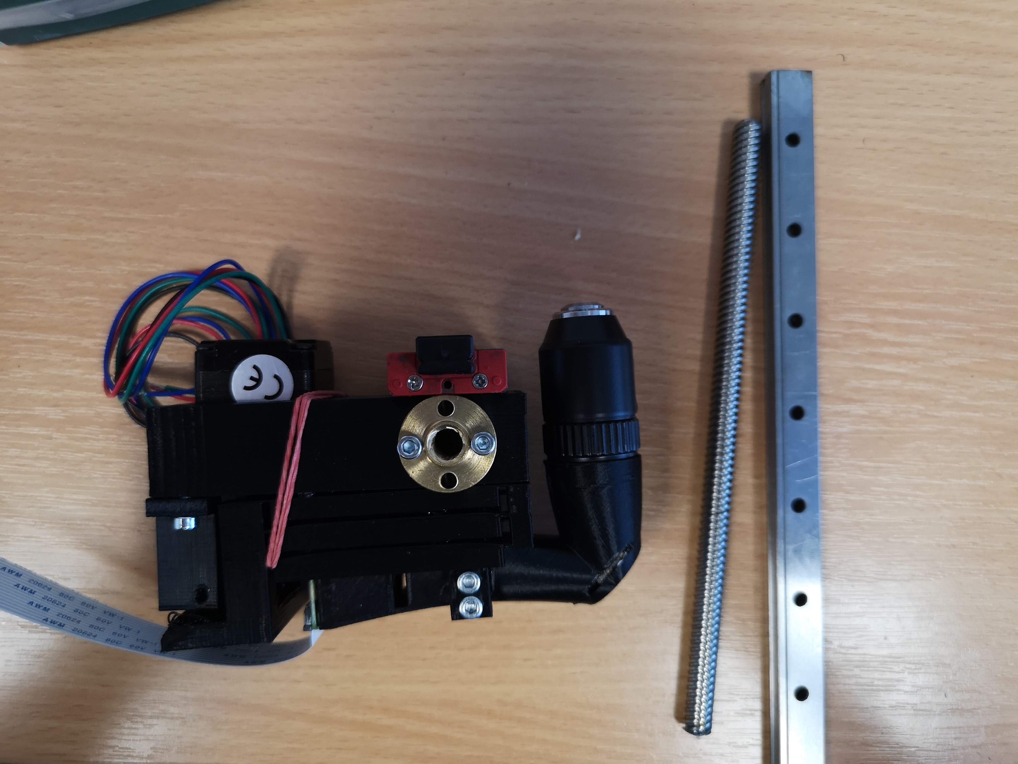
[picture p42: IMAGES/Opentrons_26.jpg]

</p>

<p align="left">
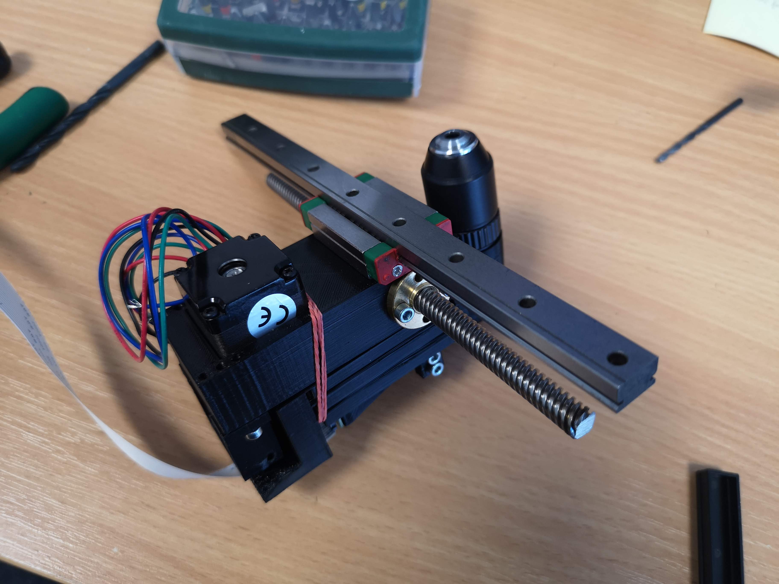
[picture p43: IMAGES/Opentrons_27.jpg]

</p>

### Assembling the X-slide 

<p align="left">
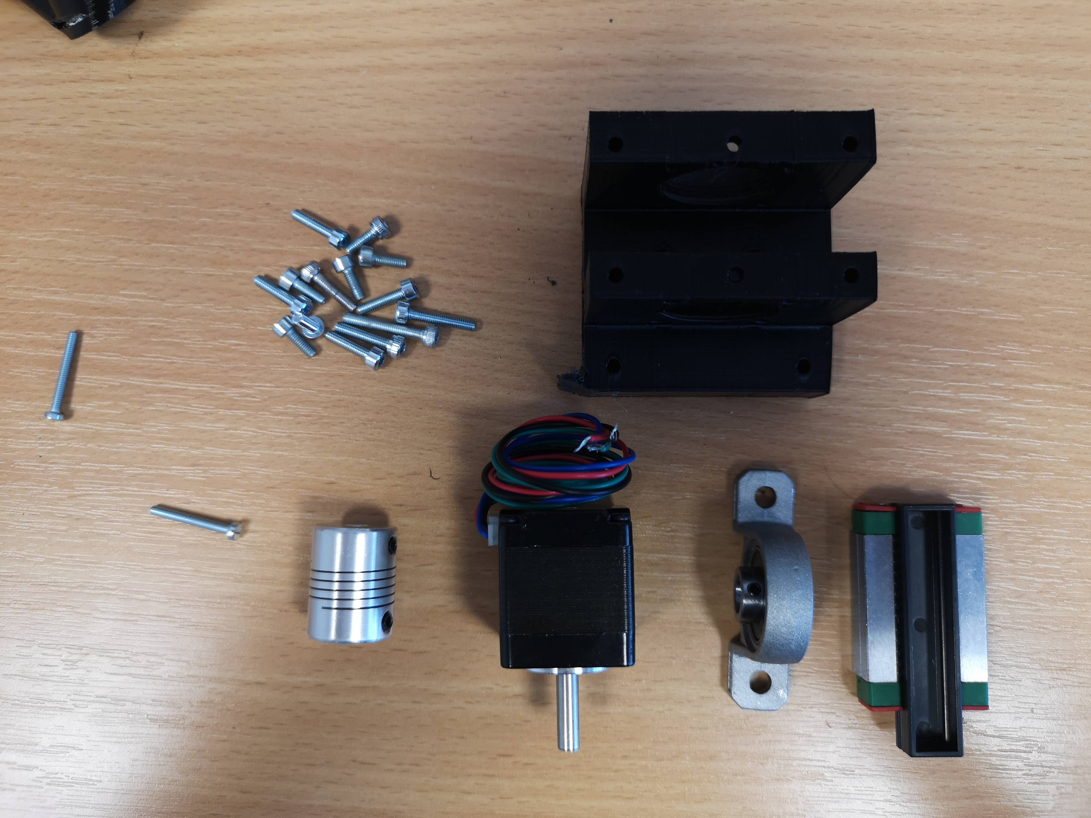
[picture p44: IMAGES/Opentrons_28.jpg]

</p>

<p align="left">
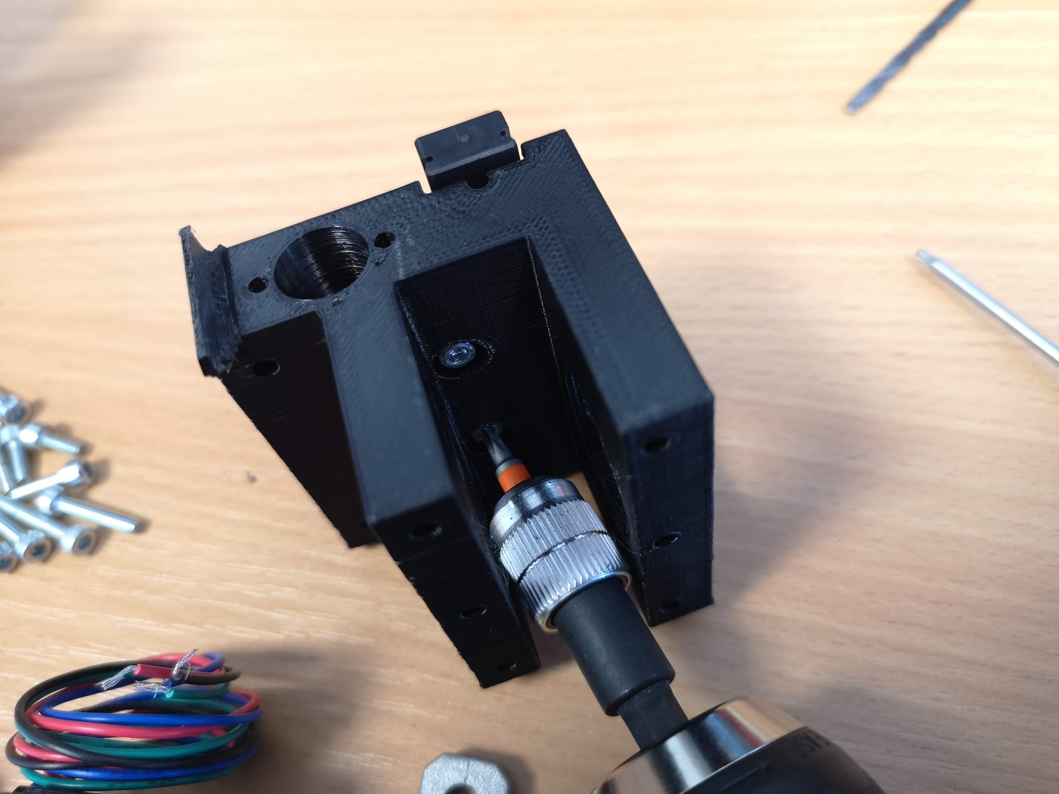
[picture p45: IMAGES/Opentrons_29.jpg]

</p>

<p align="left">
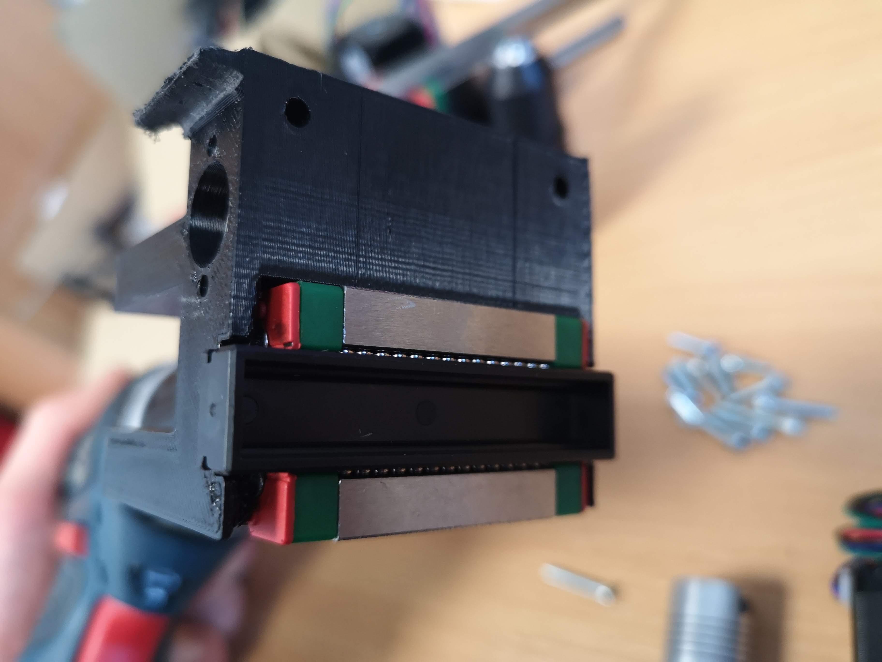
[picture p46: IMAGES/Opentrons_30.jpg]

</p>

<p align="left">
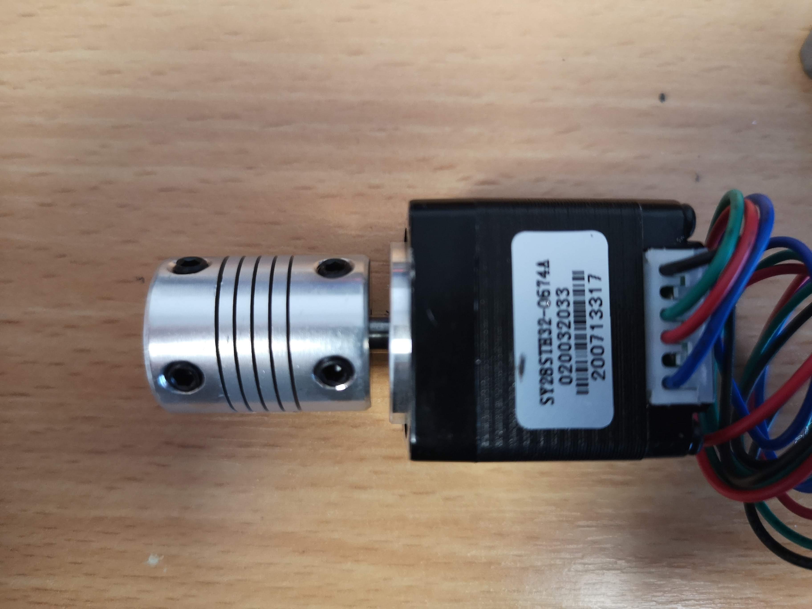
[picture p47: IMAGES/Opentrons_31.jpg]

</p>

<p align="left">
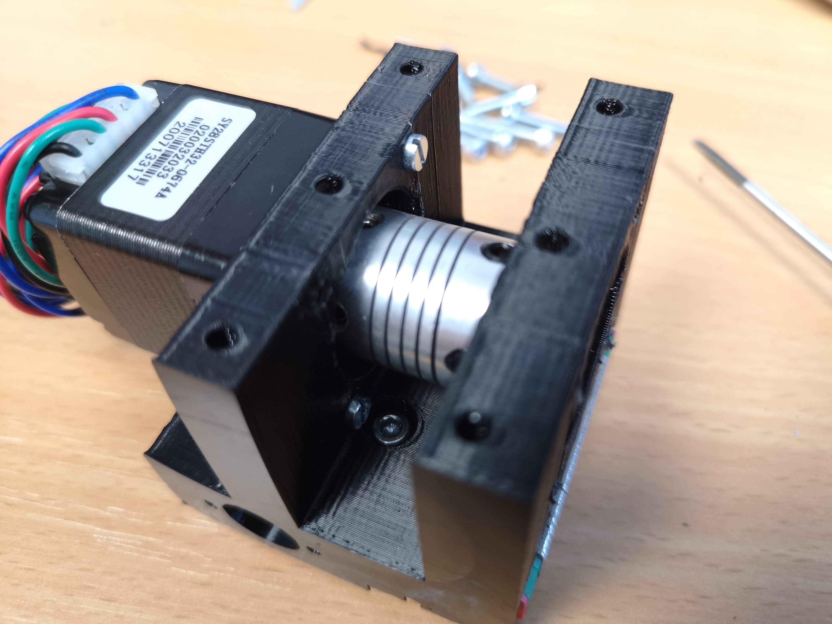
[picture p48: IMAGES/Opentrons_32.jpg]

</p>

<p align="left">

</p>

<p align="left">
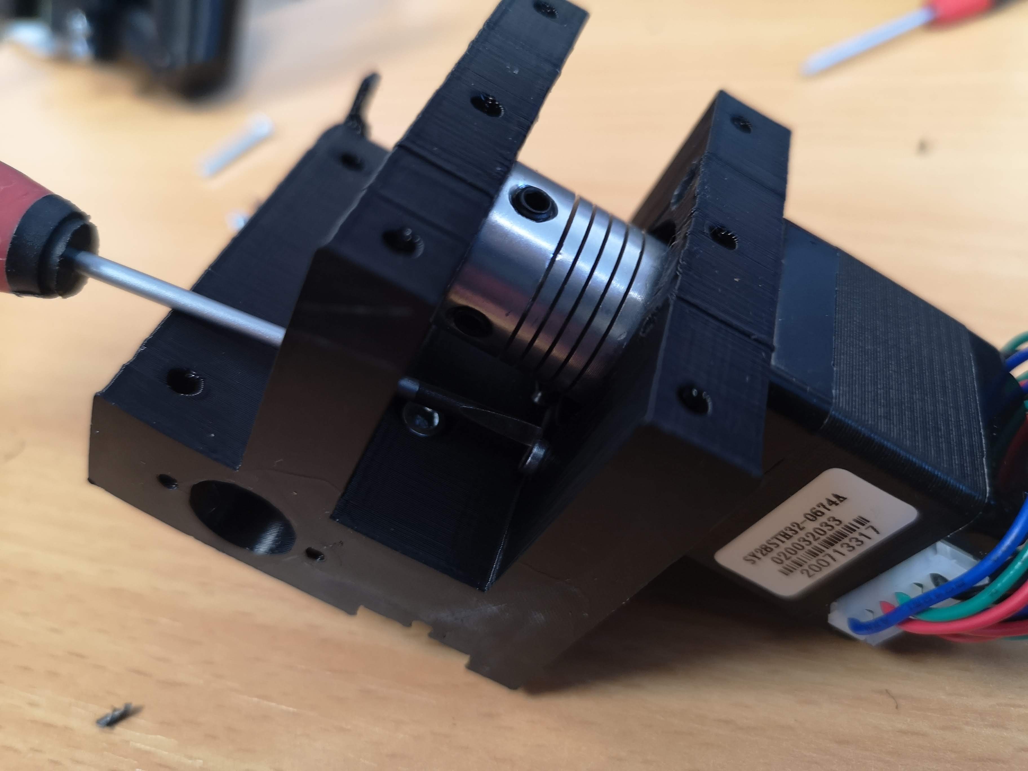
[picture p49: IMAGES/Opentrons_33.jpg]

</p>

<p align="left">
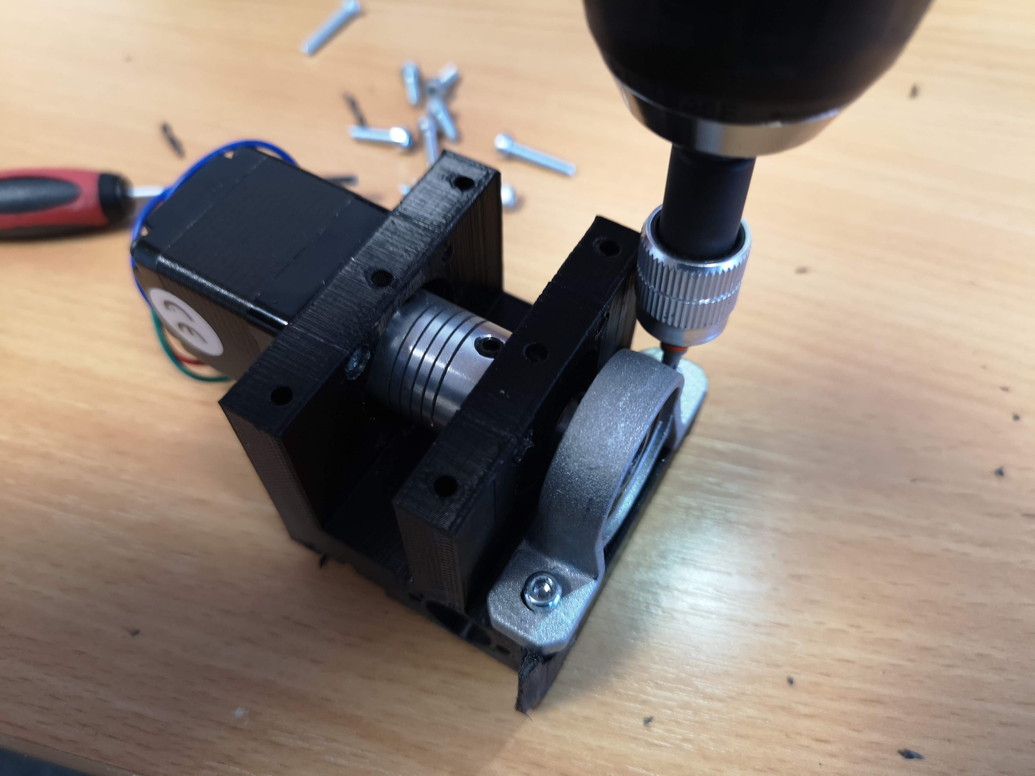
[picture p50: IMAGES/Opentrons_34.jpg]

</p>

<p align="left">
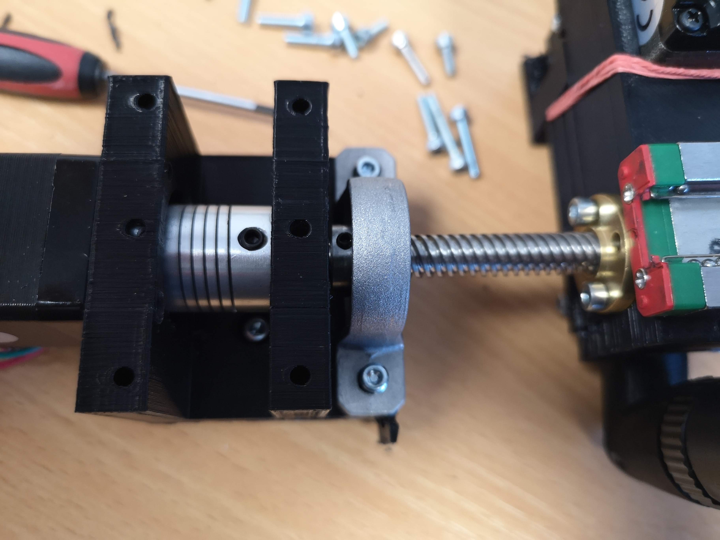
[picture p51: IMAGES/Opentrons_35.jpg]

</p>

<p align="left">
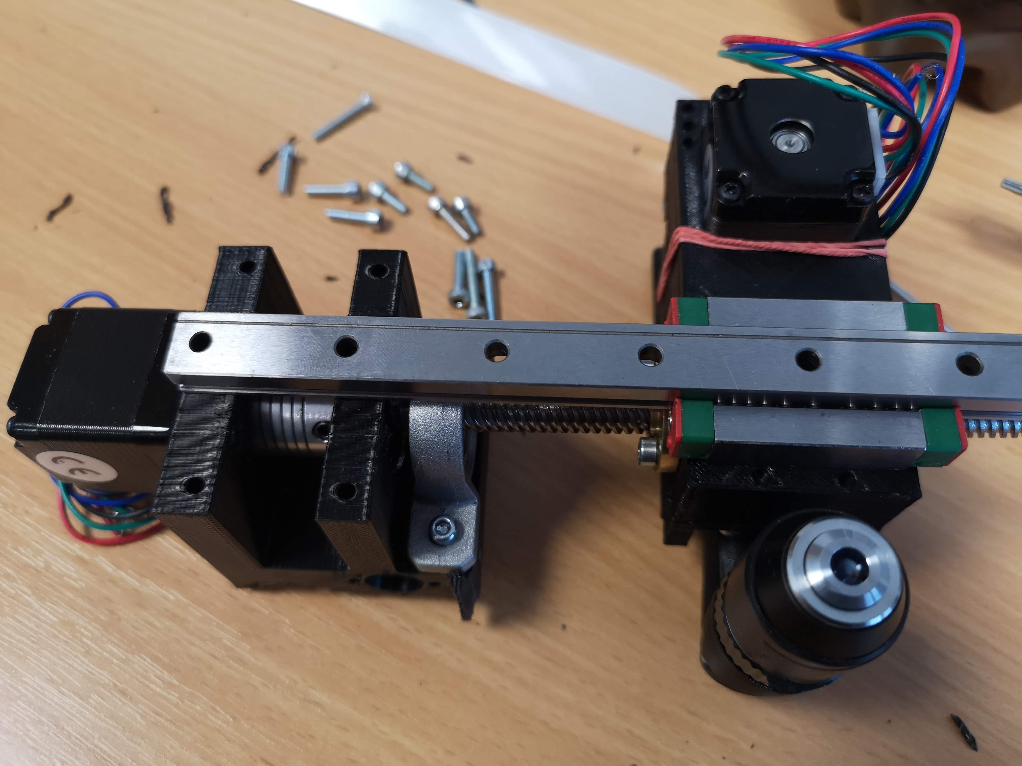
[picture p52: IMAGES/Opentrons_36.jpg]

</p>

<p align="left">
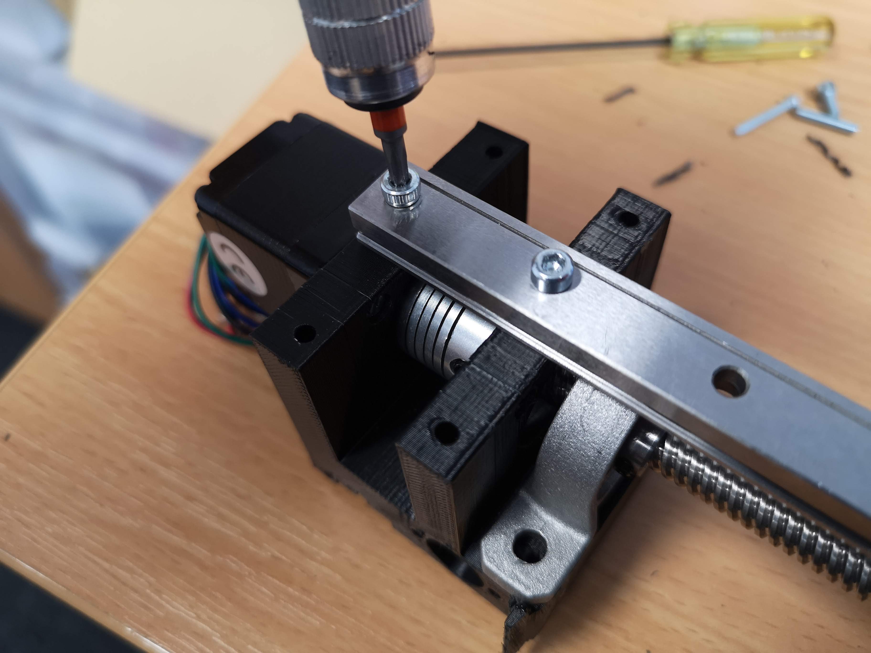
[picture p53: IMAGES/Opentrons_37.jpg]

</p>

### Assembling the XY Base

<p align="left">
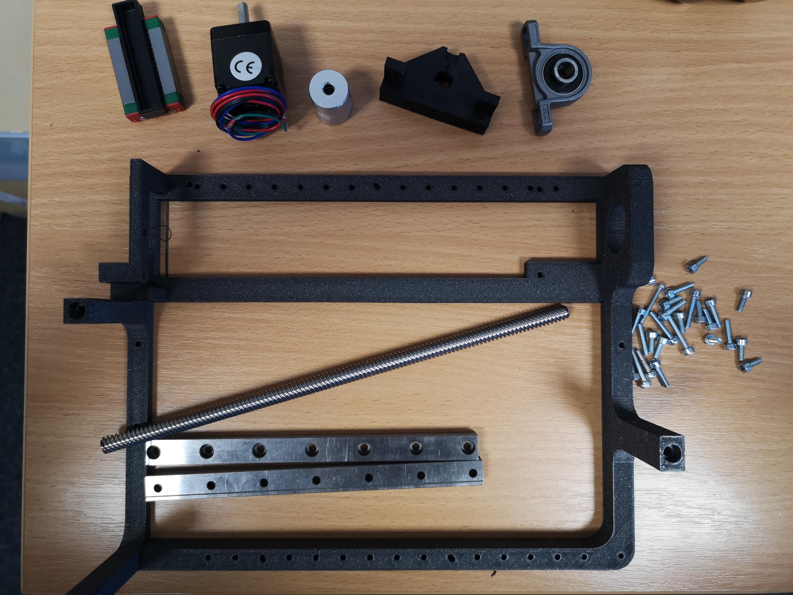
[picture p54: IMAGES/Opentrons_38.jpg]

</p>

<p align="left">
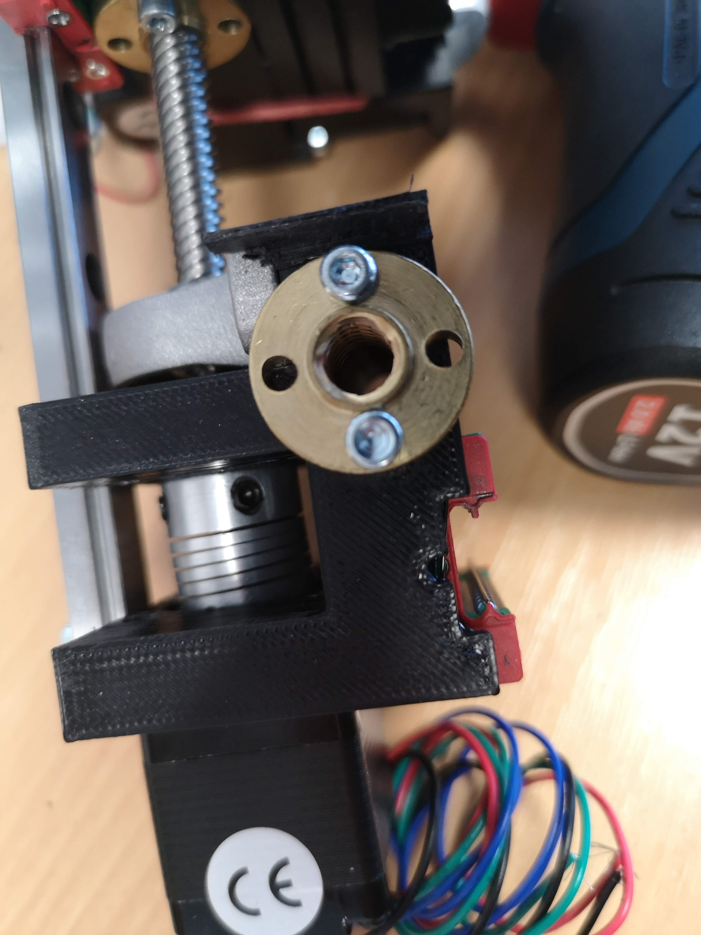
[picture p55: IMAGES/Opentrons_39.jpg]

</p>

<p align="left">
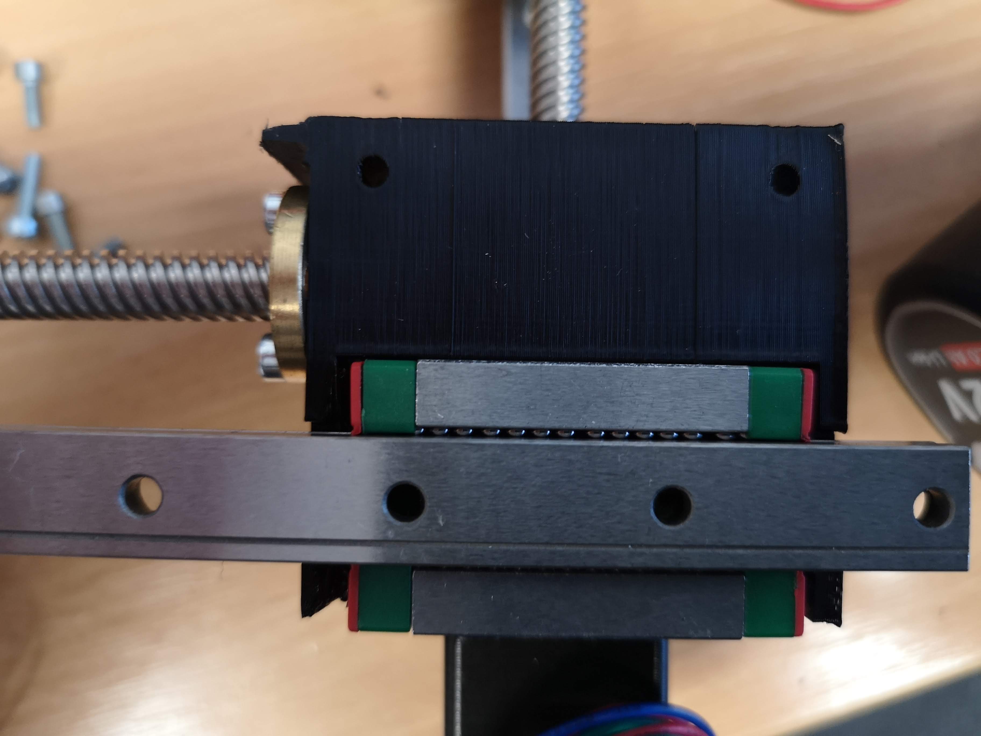
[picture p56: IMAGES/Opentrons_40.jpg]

</p>

<p align="left">

</p>

<p align="left">

</p>

<p align="left">

</p>

<p align="left">

</p>

<p align="left">

</p>

<p align="left">

</p>

<p align="left">

</p>

<p align="left">

</p>

<p align="left">

</p>

<p align="left">

</p>

<p align="left">

</p>

<p align="left">

</p>

<p align="left">

</p>

<p align="left">

</p>

<p align="left">

</p>

<p align="left">

</p>

<p align="left">

</p>

<p align="left">

</p>

### Assembling Electronics

<p align="left">

</p>

<p align="left">

</p>

<p align="left">

</p>

<p align="left">

</p>

<p align="left">

</p>

<p align="left">

</p>

<p align="left">

</p>

<p align="left">

</p>

### Finalization 

<p align="left">

</p>

<p align="left">

</p>

<p align="left">

</p>

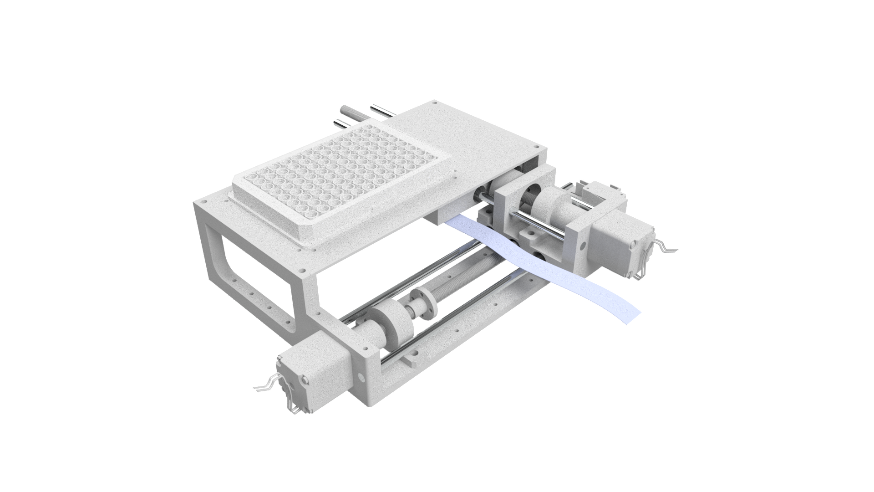
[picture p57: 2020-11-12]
IMAGES/Assembly_Opentrons_Imagingunit_v0.png

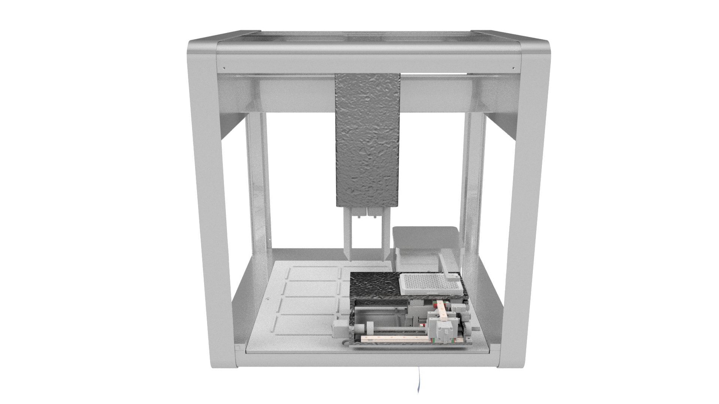
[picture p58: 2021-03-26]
INVENTOR/Assembly_Opentrons_Microscope.png

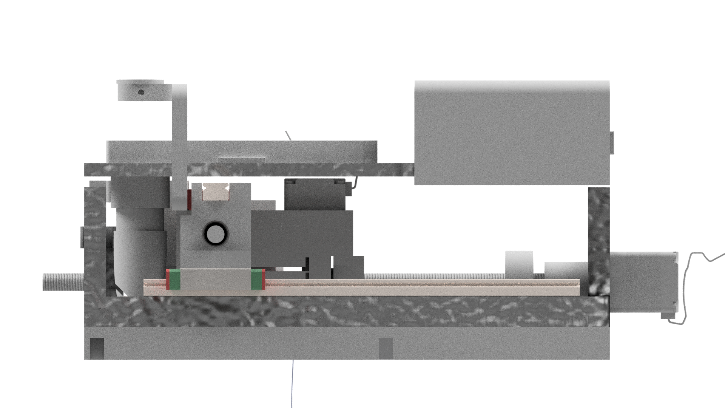
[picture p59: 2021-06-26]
INVENTOR/Assembly_Opentrons_Imagingunit_v3_front.png

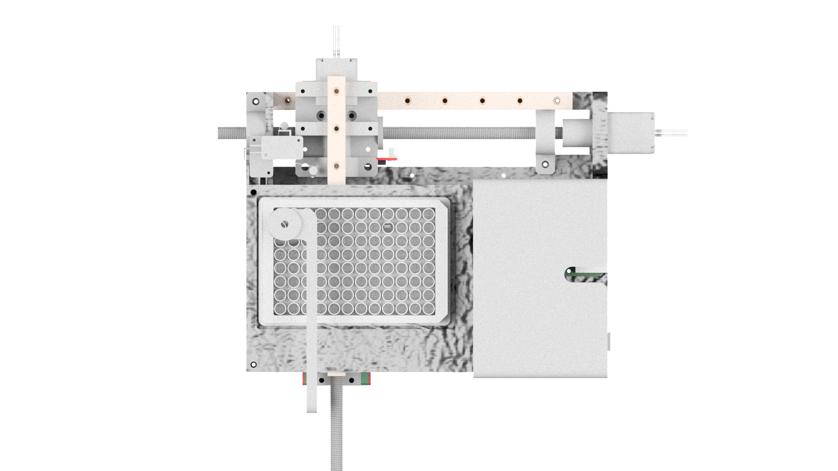
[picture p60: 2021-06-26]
INVENTOR/Assembly_Opentrons_Imagingunit_v3_top.png

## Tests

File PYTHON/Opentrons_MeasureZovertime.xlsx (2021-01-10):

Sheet: Tabelle1
My Max Val: 54872 at pos: 10 | My | Max | Val: | 54872 | at | pos:
My Max Val: 54846 at pos: 10 | My | Max | Val: | 54846 | at | pos:
My Max Val: 54683 at pos: 10 | My | Max | Val: | 54683 | at | pos:
My Max Val: 54886 at pos: 10 | My | Max | Val: | 54886 | at | pos:
My Max Val: 54810 at pos: 10 | My | Max | Val: | 54810 | at | pos:
My Max Val: 54861 at pos: 10 | My | Max | Val: | 54861 | at | pos:
My Max Val: 54920 at pos: 10 | My | Max | Val: | 54920 | at | pos:
My Max Val: 54817 at pos: 10 | My | Max | Val: | 54817 | at | pos:
My Max Val: 54804 at pos: 10 | My | Max | Val: | 54804 | at | pos:
My Max Val: 54686 at pos: 10 | My | Max | Val: | 54686 | at | pos:
My Max Val: 54857 at pos: 10 | My | Max | Val: | 54857 | at | pos:
My Max Val: 54811 at pos: 10 | My | Max | Val: | 54811 | at | pos:
My Max Val: 54859 at pos: 10 | My | Max | Val: | 54859 | at | pos:
My Max Val: 54930 at pos: 10 | My | Max | Val: | 54930 | at | pos:
My Max Val: 54795 at pos: 10 | My | Max | Val: | 54795 | at | pos:
My Max Val: 54750 at pos: 10 | My | Max | Val: | 54750 | at | pos:
My Max Val: 54732 at pos: 10 | My | Max | Val: | 54732 | at | pos:
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

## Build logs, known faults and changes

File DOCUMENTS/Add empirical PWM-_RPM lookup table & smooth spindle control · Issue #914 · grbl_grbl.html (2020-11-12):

Skip to content (https://github.com/grbl/grbl/issues/914#start-of-content)

(https://github.com/)



- 
  In this repository All GitHub ↵
  Jump to ↵
- No suggested jump to results
- 
  In this repository All GitHub ↵
  Jump to ↵
- 
  In this repository All GitHub ↵
  Jump to ↵
- Octocat Spinner Icon

(https://github.com/)

(https://github.com/notifications)

New repository (https://github.com/new) Import repository (https://github.com/new/import) New gist (https://gist.github.com/) New organization (https://github.com/organizations/new)

This repository

New issue (https://github.com/grbl/grbl/issues/new/choose)

@beniroquai

Signed in as beniroquai (https://github.com/beniroquai)

Set status

### Edit status

Could not update your status, please try again.

80 remaining

#### Suggestions:

🌴

On vacation

🤒

Out sick

🏠

Working from home

🎯

Focusing

Busy

When others mention you, assign you, or request your review, GitHub will let them know that you have limited availability.

Clear status

Never

- Never
  Keep this status until you clear your status or edit your status.
- in 30 minutes
- in 1 hour
- in 4 hours
- today
- this week

Set status Clear status

Your profile (https://github.com/beniroquai) Your repositories (https://github.com/beniroquai?tab=repositories) Your organizations (https://github.com/settings/organizations) Your projects (https://github.com/beniroquai?tab=projects) Your stars (https://github.com/beniroquai?tab=stars) Your gists (https://gist.github.com/mine)

Feature preview

Help (https://docs.github.com/) Settings (https://github.com/settings/profile) Sign out

# grbl (https://github.com/grbl) / grbl (https://github.com/grbl/grbl)

- Watch
  Notifications
  Not watching Be notified only when participating or @mentioned. Watch
  Releases only Be notified of new releases, and when participating or @mentioned. Unwatch releases
  Watching Be notified of all conversations. Unwatch
  Ignoring Never be notified. Stop ignoring
  598 (https://github.com/grbl/grbl/watchers)
- Unstar 3.8k (https://github.com/grbl/grbl/stargazers) Star 3.8k (https://github.com/grbl/grbl/stargazers)
- Fork

# Fork grbl

  If this dialog fails to load, you can visit the fork page (https://github.com/grbl/grbl/fork) directly.
  2.4k (https://github.com/grbl/grbl/network/members)

New issue (https://github.com/grbl/grbl/issues/new/choose)

Jump to bottom (https://github.com/grbl/grbl/issues/914#issue-comment-box)

# Add empirical PWM->RPM lookup table & smooth spindle control #914

Open

doppelhub (https://github.com/doppelhub) opened this issue on 24 Feb 2016 · 8 comments

Open

# Add empirical PWM->RPM lookup table & smooth spindle control (https://github.com/grbl/grbl/issues/914#) #914

doppelhub (https://github.com/doppelhub) opened this issue on 24 Feb 2016 · 8 comments

## Comments

@doppelhub (https://github.com/doppelhub)

Pick your reaction

👍 👎 😄 🎉 😕 ❤️ 🚀 👀

Copy link Quote reply

### @doppelhub (https://github.com/doppelhub) doppelhub (https://github.com/doppelhub) commented on 24 Feb 2016 (https://github.com/grbl/grbl/issues/914#issue-135997751)

I propose adding two features to spindle_control.c:
1: Slowly ramp to pwm setpoint. Most PWM motor controllers will faithfully attempt to instantaneously start or stop a motor, causing massive current inrush. See lines 139 to 149 for my proposed proof-of-concept. Since "S" commands are blocking, I don't see any concerns using delay_ms(). Note that this smoothing function ONLY works when the PWM output is active and then only with "S" commands. For example:

//motor speed was previously S10000
M5
S0

...stops PWM train immediately because the PWM output is disabled before the speed ramps down.

//motor speed was previously S10000
S0
M5

...smoothly ramps PWM duty, as desired.

2: I want the "S" speed to correlate with actual (empirical) RPM. I've added a lookup table that allows you to alter the output counter register value. See lines 63 to 98 for the lookup table, which is indexed on line 137. Note: The LUT values reflect my empirical data... you'd want to comment out line 137 until the user replaced the LUT values. This lookup table is stored in flash and doesn't consume any ram.

Yay, now my spindle ramps smoothly and doesn't pull 100A when I stop it!

Complete spindle_control.c:

/*
spindle_control.c - spindle control methods
Part of Grbl v0.9

Copyright (c) 2012-2014 Sungeun K. Jeon

Grbl is free software: you can redistribute it and/or modify
it under the terms of the GNU General Public License as published by
the Free Software Foundation, either version 3 of the License, or
(at your option) any later version.

Grbl is distributed in the hope that it will be useful,
but WITHOUT ANY WARRANTY; without even the implied warranty of
MERCHANTABILITY or FITNESS FOR A PARTICULAR PURPOSE. See the
GNU General Public License for more details.

You should have received a copy of the GNU General Public License
along with Grbl. If not, see <http://www.gnu.org/licenses/>.
*/
/*
This file is based on work from Grbl v0.8, distributed under the
terms of the MIT-license. See COPYING for more details.
Copyright (c) 2009-2011 Simen Svale Skogsrud
Copyright (c) 2012 Sungeun K. Jeon
*/

#include "system.h"
#include "spindle_control.h"
#include "protocol.h"
#include "gcode.h"

void spindle_init()
{
// On the Uno, spindle enable and PWM are shared. Other CPUs have seperate enable pin.
#ifdef VARIABLE_SPINDLE
SPINDLE_PWM_DDR |= (1<<SPINDLE_PWM_BIT); // Configure as PWM output pin.
#ifndef CPU_MAP_ATMEGA328P
SPINDLE_ENABLE_DDR |= (1<<SPINDLE_ENABLE_BIT); // Configure as output pin.
#endif
#else
SPINDLE_ENABLE_DDR |= (1<<SPINDLE_ENABLE_BIT); // Configure as output pin.
#endif
SPINDLE_DIRECTION_DDR |= (1<<SPINDLE_DIRECTION_BIT); // Configure as output pin.
spindle_stop();
}

void spindle_stop()
{
// On the Uno, spindle enable and PWM are shared. Other CPUs have seperate enable pin.
#ifdef VARIABLE_SPINDLE
TCCRA_REGISTER &= ~(1<<COMB_BIT); // Disable PWM. Output voltage is zero.
#ifndef CPU_MAP_ATMEGA328P
SPINDLE_ENABLE_PORT &= ~(1<<SPINDLE_ENABLE_BIT); // Set pin to low.
#endif
#else
SPINDLE_ENABLE_PORT &= ~(1<<SPINDLE_ENABLE_BIT); // Set pin to low.
#endif
}

//LUT to find corresponding PWM->RPM register value
//Substitutes requested 8bit PWM counter value with empirical RPM data
static const __flash uint8_t lookup[256] = {
0, 0, 59, 67, 73, 78, 82, 86,
89, 93, 96, 98, 101, 103, 106, 108,
110, 112, 114, 116, 118, 119, 121, 123,
124, 126, 127, 129, 130, 132, 133, 134,
136, 137, 138, 139, 141, 142, 143, 144,
145, 146, 147, 148, 149, 150, 151, 152,
153, 154, 155, 156, 157, 158, 159, 160,
161, 162, 162, 163, 164, 165, 166, 166,
167, 168, 169, 170, 170, 171, 172, 173,
173, 174, 175, 176, 176, 177, 178, 178,
179, 180, 180, 181, 182, 182, 183, 184,
184, 185, 186, 186, 187, 187, 188, 189,
189, 190, 190, 191, 192, 192, 193, 193,
194, 194, 195, 196, 196, 197, 197, 198,
198, 199, 199, 200, 200, 201, 201, 202,
203, 203, 204, 204, 205, 205, 206, 206,
207, 207, 208, 208, 208, 209, 209, 210,
210, 211, 211, 212, 212, 213, 213, 214,
214, 215, 215, 215, 216, 216, 217, 217,
218, 218, 219, 219, 219, 220, 220, 221,
221, 222, 222, 222, 223, 223, 224, 224,
224, 225, 225, 226, 226, 226, 227, 227,
228, 228, 228, 229, 229, 230, 230, 230,
231, 231, 231, 232, 232, 233, 233, 233,
234, 234, 234, 235, 235, 236, 236, 236,
237, 237, 237, 238, 238, 238, 239, 239,
240, 240, 240, 241, 241, 241, 242, 242,
242, 243, 243, 243, 244, 244, 244, 245,
245, 245, 246, 246, 246, 247, 247, 247,
248, 248, 248, 249, 249, 249, 250, 250,
250, 251, 251, 251, 252, 252, 252, 252,
253, 253, 253, 254, 254, 254, 255, 255
};

void spindle_run(uint8_t direction, float rpm)
{
if (sys.state == STATE_CHECK_MODE) { return; }

// Empty planner buffer to ensure spindle is set when programmed.
protocol_auto_cycle_start(); //temp fix for M3 lockup
protocol_buffer_synchronize();

// Halt or set spindle direction and rpm.
if (direction == SPINDLE_DISABLE) {

spindle_stop();

} else {

if (direction == SPINDLE_ENABLE_CW) {
SPINDLE_DIRECTION_PORT &= ~(1<<SPINDLE_DIRECTION_BIT);
} else {
SPINDLE_DIRECTION_PORT |= (1<<SPINDLE_DIRECTION_BIT);
}

#ifdef VARIABLE_SPINDLE
// TODO: Install the optional capability for frequency-based output for servos.
#define SPINDLE_RPM_RANGE (SPINDLE_MAX_RPM-SPINDLE_MIN_RPM)
TCCRA_REGISTER = (1<<COMB_BIT) | (1<<WAVE1_REGISTER) | (1<<WAVE0_REGISTER);
TCCRB_REGISTER = (TCCRB_REGISTER & 0b11111000) | 0x02; // set to 1/8 Prescaler
if ( rpm < SPINDLE_MIN_RPM ) { rpm = 0; }
else {
rpm -= SPINDLE_MIN_RPM;
if ( rpm > SPINDLE_RPM_RANGE ) { rpm = SPINDLE_RPM_RANGE; } // Prevent uint8 overflow
}
uint8_t setpoint_pwm = floor( rpm*(255.0/SPINDLE_RPM_RANGE) + 0.5);
#ifdef MINIMUM_SPINDLE_PWM
if (setpoint_pwm < MINIMUM_SPINDLE_PWM) { setpoint_pwm = MINIMUM_SPINDLE_PWM; }
#endif

setpoint_pwm=lookup[setpoint_pwm]; //LUT to find corresponding PWM->RPM register value

uint8_t current_pwm = OCR_REGISTER; //get previous PWM register value
while(current_pwm != setpoint_pwm) {
if(current_pwm > setpoint_pwm) {
current_pwm -= 1;
} else {
current_pwm += 1;
}

OCR_REGISTER = current_pwm; // Set PWM pin output
delay_ms(2);
}

#ifndef CPU_MAP_ATMEGA328P // On the Uno, spindle enable and PWM are shared.
SPINDLE_ENABLE_PORT |= (1<<SPINDLE_ENABLE_BIT);
#endif
#else
SPINDLE_ENABLE_PORT |= (1<<SPINDLE_ENABLE_BIT);
#endif

}
}

Pick your reaction

👍 👎 😄 🎉 😕 ❤️ 🚀 👀

@rwensley (https://github.com/rwensley)

Pick your reaction

👍 👎 😄 🎉 😕 ❤️ 🚀 👀

Loading…

Sorry, something went wrong.

@rwensley (https://github.com/rwensley) rwensley (https://github.com/rwensley) commented on 24 Feb 2016 (https://github.com/grbl/grbl/issues/914#issuecomment-188306059)

I agree completely. I have been working toward this same idea but time slows me down. The universal motors are highly non-linear and do not like to be stopped at full voltage. Both of these options will be a great benefit.

Every router will have a different curve that will need to be put into the lookup table. Perhaps a small utility that could aid the user in determining that curve and then incorporate it into the spindle_control.c routine.

Pick your reaction

👍 👎 😄 🎉 😕 ❤️ 🚀 👀

@chamnit (https://github.com/chamnit)

Pick your reaction

👍 👎 😄 🎉 😕 ❤️ 🚀 👀

Loading…

Sorry, something went wrong.

Member

### @chamnit (https://github.com/chamnit) chamnit (https://github.com/chamnit) commented on 24 Feb 2016 (https://github.com/grbl/grbl/issues/914#issuecomment-188307440)

@doppelhub (https://github.com/doppelhub) : Thanks for the code proposal. I'll dive right into my thoughts on them. First, delay_ms() absolutely cannot be used with spindle control, because real-time spindle overrides will be broken (written, working, but not published). It's not a good idea to use a blocking delay function, if it at all possible.

Second, you're not the first person to suggest more precise spindle control. Basically my answer was that its not Grbl's job to determine how a spindle should behave. Only that it should output consistent and predicable signals to indicate on/off and the desired RPM. A separate spindle controller should be the one performing the tasks to ensure the spindle is running at the correct RPM and does so smoothly to avoid the amps problem you mentioned.

That said, I recognize that sometimes users have spindle controllers that they can't alter, so the only solution is to alter the spindle control output, as you do in your code proposal. It's a solution, but it's not a general solution that will work for everyone. There are numerous ways of approaching this problem and hence numerous solutions. For now, I think it's still prudent to use a separate controller to interpret Grbl's signals, which can be done by a simple $5-$10 Arduino Mini with a quick Arduino IDE program.

@rwensley (https://github.com/rwensley) : To expand on the idea that every router and universal motors are different and highly nonlinear, this further solidifies the idea that a spindle controller should be separate. A dedicated MCU that can be easily modified, updated, and configured for each particular spindle, open-loop or closed-loop, is the best option. It removes risks of creating bugs in the main Grbl firmware or overcomplicating things. It allows an infinite amount of flexibility. This also allows the use of closed-loop spindle controllers that ensure the spindle maintains the correct RPM when under load, which definitely needs a robust, dedicated controller to monitor the spindle at a high refresh rate.

Pick your reaction

👍 👎 😄 🎉 😕 ❤️ 🚀 👀

@doppelhub (https://github.com/doppelhub)

Pick your reaction

👍 👎 😄 🎉 😕 ❤️ 🚀 👀

Loading…

Sorry, something went wrong.

Author

@doppelhub (https://github.com/doppelhub) doppelhub (https://github.com/doppelhub) commented on 24 Feb 2016 (https://github.com/grbl/grbl/issues/914#issuecomment-188394057)

Thanks for the informative replies!
Sonny, as long as I don't use real-time spindle overrides, delay_ms() is fine, correct?
I ask because I wrote this code to update the 1500 CNC machines we've already shipped... we certainly don't want to have to add additional hardware.

FYI: I've also created code (external to grbl) that automatically calibrates "S" speed to actual RPM. To do this, in manufacturing we temporarily connect a hall sensor to the counter on pin 9. The code then steps through each PWM register value, logs the frequency, then builds the LUT.

Pick your reaction

👍 👎 😄 🎉 😕 ❤️ 🚀 👀

@chamnit (https://github.com/chamnit)

Pick your reaction

👍 👎 😄 🎉 😕 ❤️ 🚀 👀

Loading…

Sorry, something went wrong.

Member

### @chamnit (https://github.com/chamnit) chamnit (https://github.com/chamnit) commented on 24 Feb 2016 (https://github.com/grbl/grbl/issues/914#issuecomment-188398350)

@doppelhub (https://github.com/doppelhub) : For the delay_ms(), I can't guarantee that it won't be a problem, especially in the future with v1.0. As far as helping you to support 1500 CNC machines, most of my time is invested in supporting official Grbl sponsors and the rest of it is in developing v1.0 and helping users. I can't ensure backward compatibility for you later if you went ahead with this. Nor can I ensure that there will be any room for this code in v1.0, as it's looking to completely use all the remaining flash space in the 328p.

Pick your reaction

👍 👎 😄 🎉 😕 ❤️ 🚀 👀

@doppelhub (https://github.com/doppelhub)

Pick your reaction

👍 👎 😄 🎉 😕 ❤️ 🚀 👀

Loading…

Sorry, something went wrong.

Author

@doppelhub (https://github.com/doppelhub) doppelhub (https://github.com/doppelhub) commented on 24 Feb 2016 (https://github.com/grbl/grbl/issues/914#issuecomment-188401791)

It's short-sided on our part, but we're still using 0.9g and don't plan on updating anytime soon. I looked through 0.9g's architecture and didn't see any way delay_ms() could get us when changing the spindle speed. I accept the risk. FYI: We didn't see any issues with this code in our V&V.

Also, what do we need to do to become an official sponsor? Probably more than the $30 I sent you last year, right ;)? Probably time for another donation. As always, thanks for your commitment to grbl!

Pick your reaction

👍 👎 😄 🎉 😕 ❤️ 🚀 👀

@langwadt (https://github.com/langwadt)

Pick your reaction

👍 👎 😄 🎉 😕 ❤️ 🚀 👀

Loading…

Sorry, something went wrong.

@langwadt (https://github.com/langwadt) langwadt (https://github.com/langwadt) commented on 24 Feb 2016 (https://github.com/grbl/grbl/issues/914#issuecomment-188471978)

is it normal procedure that you have to manually add dwells to the gcode to take spindle spinup time into account?

Pick your reaction

👍 👎 😄 🎉 😕 ❤️ 🚀 👀

@doppelhub (https://github.com/doppelhub)

Pick your reaction

👍 👎 😄 🎉 😕 ❤️ 🚀 👀

Loading…

Sorry, something went wrong.

Author

@doppelhub (https://github.com/doppelhub) doppelhub (https://github.com/doppelhub) commented on 26 Feb 2016 (https://github.com/grbl/grbl/issues/914#issuecomment-189053285)

Yes. If your spindle takes a while to spin up, then you'll need to dwell. grbl doesn't wait at all... just updates the PWM and then executes the next line of code.

Pick your reaction

👍 👎 😄 🎉 😕 ❤️ 🚀 👀

@csdexter (https://github.com/csdexter)

Pick your reaction

👍 👎 😄 🎉 😕 ❤️ 🚀 👀

Loading…

Sorry, something went wrong.

@csdexter (https://github.com/csdexter) csdexter (https://github.com/csdexter) commented on 26 Feb 2016 (https://github.com/grbl/grbl/issues/914#issuecomment-189053588)

... which is why in the pro world you have a line called "SPINDLE_AT_SPEED" coming from the spindle controller back into the generic CNC controller to hint the latter it can resume execution after an S word (IIRC the G-Code explicitly mentions that the controller should do that if it can technically detect the current spindle speed).

Pick your reaction

👍 👎 😄 🎉 😕 ❤️ 🚀 👀

@beniroquai (https://github.com/beniroquai)

Write Preview

Select a reply ctrl .

There was an error creating your Issue.

Attach files by dragging & dropping, selecting or pasting them.  Uploading your files… We don’t support that file type. Try again with a GIF, JPEG, JPG, PNG, DOCX, GZ, LOG, PDF, PPTX, TXT, XLSX or ZIP. Attaching documents requires write permission to this repository. Try again with a GIF, JPEG, JPG, PNG, DOCX, GZ, LOG, PDF, PPTX, TXT, XLSX or ZIP. We don’t support that file type. Try again with a GIF, JPEG, JPG, PNG, DOCX, GZ, LOG, PDF, PPTX, TXT, XLSX or ZIP. Yowza, that’s a big file Try again with a file smaller than 10MB. This file is empty. Try again with a file that’s not empty. This file is hidden. Try again with another file. Something went really wrong, and we can’t process that file. Try again. (https://guides.github.com/features/mastering-markdown/)

Nothing to preview

Comment

Remember, contributions to this repository should follow our GitHub Community Guidelines (https://docs.github.com/articles/github-community-guidelines).

Assignees

No one assigned

Labels

None yet

Projects

None yet

Milestone

No milestone

Linked pull requests

Successfully merging a pull request may close this issue.

None yet

Notifications

Customize

### Notification settings

Loading...

Subscribe

You’re not receiving notifications from this thread.

5 participants

@chamnit (https://github.com/chamnit) @csdexter (https://github.com/csdexter) @langwadt (https://github.com/langwadt) @doppelhub (https://github.com/doppelhub) @rwensley (https://github.com/rwensley)

(https://github.com/)

- © 2020 GitHub, Inc.
- Terms (https://github.com/site/terms)
- Privacy (https://github.com/site/privacy)
- Cookie Preferences
- Security (https://github.com/security)
- Status (https://githubstatus.com/)
- Help (https://docs.github.com/)
- Contact GitHub (https://github.com/contact)
- Pricing (https://github.com/pricing)
- API (https://docs.github.com/)
- Training (https://services.github.com/)
- Blog (https://github.blog/)
- About (https://github.com/about)

You can’t perform that action at this time.

We use optional third-party analytics cookies to understand how you use GitHub.com so we can build better products. Learn more.

Accept Reject

We use optional third-party analytics cookies to understand how you use GitHub.com so we can build better products.
You can always update your selection by clicking Cookie Preferences at the bottom of the page. For more information, see our Privacy Statement (https://docs.github.com/en/free-pro-team@latest/github/site-policy/github-privacy-statement).

##### Essential cookies

We use essential cookies to perform essential website functions, e.g. they're used to log you in. Learn more (https://docs.github.com/en/github/site-policy/github-subprocessors-and-cookies)

##### Always active

##### Analytics cookies

We use analytics cookies to understand how you use our websites so we can make them better, e.g. they're used to gather information about the pages you visit and how many clicks you need to accomplish a task. Learn more (https://docs.github.com/en/github/site-policy/github-subprocessors-and-cookies)

Accept Reject

Save preferences

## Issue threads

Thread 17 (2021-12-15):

Hardware list links are brokens

Tarzter, 2021-12-15:
Hi,
Some of the links are broken, most of them I could find by googling,
I couldn't find the "CCTV Linse", and which wires are required.
Could you please help me with finding/provide a recommended Lense to purchase?
thanks!

- [ ]

beniroquai, 2021-12-18:
Hey @Tarzter,

thanks for reaching out! The lens was only used for a special voice-coil-based focusing mechanism. Not sure if you really want to recreate that one? I must admit that the current documentation may not reflect the final build. What exactly do you envision to build in the end? Perhaps I can guide you through the process.

Tarzter, 2021-12-19:
Thank you for the quick response!
I would like to recreate the "Opentrons Imaging Unit" - I want to embed automatic microscopy photage inside the opentrons OT-2,
I saw your other project Hi2 but it seemed like a more complicated one (correct me if I'm wrong) - because of the UT2 microscope - requiring to order parts that are harder to find (most of the shops in the links ships to germany and not world wide, ).

What would you recommend?
Currently I've ordered parts from the list and some parts that I saw in the assembly pictures which were missing (Limit switch, 10x optical microscope lens, and bunch of wires)

beniroquai, 2022-01-07:
Hey, sorry for late reply. Holiday season :-)
I think the microscope here is a good first start. It gives you a fully working wellplate scanning microscope without the need to assemble UC2 components. May I ask you what you want to do with it? Depending on what you want to do, perhaps another easy thing would be to buy a laser engraver and a cheap USB microscope and create a cheap wellplate scanning microscope?

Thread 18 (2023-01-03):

Unable to install the system correctly

bichar4, 2023-01-03:
Hi,
I was trying to setup the opentrons-grbl server system and tried following the steps as mentioned in the readme file. Basically , what I did was the following:
- Boot [OpenFlexure Lite image](https://build.openflexure.org/raspbian-openflexure/armhf/lite/latest) and connected it via ssh
- Followed the following steps as mentioned:
```
cd ~
git clone -b opentrons-grbl https://gitlab.com/beniroquai/openflexure-microscope-server
cd openflexure-microscope-server/openflexure_microscope/api
ATTENTION:
sudo rm -r static # we need to rebuild it this takes long, so we side-load it by building it on a computer or downloading it here:
wget static.zip # link will follow; gdrive: https://drive.google.com/file/d/1I15lDKNll91UxbFlYPiCGbfkYkHK_CM1/view?usp=sharing
unzip static.zip
```
- ofm stop the previously installed server
- Setup the settings in ~/openflexure-microscope-server/openflexure_microscope/openflexure/settings as mentioned

Now the problem is that, whenever I try to run the new server that is located at  ~/openflexure-microscope-server/openflexure_microscope/api , the imported module inside app.py always points to the one that is located at /var/openflexure/application/openflexure-microscope-server. Due to this , when trying to set the stage type to 'grbl', I am getting error. Am I missing something while setting up the system?

Thanks,

beniroquai, 2023-01-03:
Hey @bichar4, thanks for reaching out. I must admit that I wasn't working on this project for a while now. I remember that @rwb27 put some efforts into creating a better integration of external hardware modules into the OFM server. Perhaps we could use this mechanism to inject the GRBL mechanism again?
A better guess would be to use the latest OFM server you already showed and try to replace the Sangaboard with the GRBL implementation.

Hope that helps :)

rwb27, 2023-01-21:
Hi all, the changes I made to modularise the server are, unfortunately, all still in a development branch - from memory you'll need to hack the Python code of the server module in order to use a stage that's not built in. I'm pretty sure @beniroquai did that.

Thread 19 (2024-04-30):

Help Needed: Preinstalled image for OFM using a Nvidia Jetson Nano

jsmithe2, 2024-04-30:
Hello,

I am trying to emulate the exact UC2-Hi2 microscope you made to integrate into an opentrons system. I have purchased all the parts required for this and I am having trouble connecting them. I am using a Jetson Nano, a CMOS camera and and a Neje master 2 mini. You posted a warning in the README section of the Hi2 repository that looks like this:

_**"Warning: This is still under strong development. We derived the software to control the GRBL-based XYZt stage from the [Openflexure microscope project](https://gitlab.com/beniroquai/openflexure-microscope-server) by Bowman et al. Instead of using a Raspberry Pi camera, we use an Nvidia Jetson Nano singleboard computer and run a customized version of the OFM server that can control the GRBL board and the monochrome CMOS camera.

A detailed set of instructions for installing the Openflexure Server (OFM Server) can be found in a dedicated [README_SOFTWARE.md](https://github.com/openUC2/UC2-Hi2/blob/master/README_SOFTWARE.md) (it is under construction..). In case you want a preinstalled image, please contact us!"**_

Is there a preinstalled image for a custom OFM server preinstalled image that would work best for this? Is this posted anywhere? This warning makes me skeptical that I'll be able to get this to work now that I have collected all of the necessary parts.

jsmithe2, 2024-04-30:
Is the correct image included in the paper "An Open-Source Modular Framework for Automated Pipetting and Imaging Applications"? There was a Zenodo link with a file named 'openflexure-microscope-server-opentrons-grbl.zip'. Is the correct one to install on the Jetson Nano?

beniroquai, 2024-04-30:
Hey @jsmithe2, sorry for my late reply (also on the other github issue I saw). I must admit that this project is already fairly old and I am working on an updated version, which using a different software. It's called ImSwitch and can also run on the Jetson. I have gained a lot of experiences, both in hard- and software and improved it quiet a lot. We don't use the openflexure software anymore. I think it would not be too difficult to add a stage controller for the Neje stage to ImSwitch. Are you familiar with python programming?
the software I'm talking about can be found here: https://github.com/openUC2/ImSwitch/ including an installation tutorial for the jetson.

beniroquai, 2024-05-05:
So what you could do is using the CNC board with the ESP32 arduino-like board (forgot the correct name, has an Arduino UNO footprint) and flash our firmware https://openuc2.github.io/docs/Investigator/STORM/Electronics/#flashing-the-firmware
This directly integrates with the UC2-REST and ImSwitch. ImSwitch runs on your computer ([Installer](https://openuc2.github.io/docs/ImSwitch/ImSwitchInstaller/)) and we could integrate the HTTP interface from the opentrons there. Makes sense?

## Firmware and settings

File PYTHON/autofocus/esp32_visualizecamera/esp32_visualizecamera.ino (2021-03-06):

#define CAMERA_MODEL_M5STACK_PSRAM

#include "esp_camera.h"
#include "camera_pins.h"

#define FRAME_SIZE FRAMESIZE_QVGA
#define WIDTH 320
#define HEIGHT 240
#define BLOCK_SIZE 10
#define W (WIDTH / BLOCK_SIZE)
#define H (HEIGHT / BLOCK_SIZE)
#define BLOCK_DIFF_THRESHOLD 0.2
#define IMAGE_DIFF_THRESHOLD 0.1
#define DEBUG 1


uint16_t proc_frame[H][W] = { 0 };
uint16_t current_frame[H][W] = { 0 };


bool setup_camera(framesize_t);
bool capture_still();
bool convolve_gaussian();
void find_max_pix();
void print_frame(uint16_t frame[H][W]);
int max_x = 0;
int max_y = 0;
  

/**

*/
void setup() {
  Serial.begin(115200);
  Serial.println(setup_camera(FRAME_SIZE) ? "OK" : "ERR INIT");
}

/**

*/
void loop() {
  if (!capture_still()) {
    Serial.println("Failed capture");
    delay(3000);

    return;
  }

  if (convolve_gaussian()) {
    //Serial.println("convolve gaussian");
  }

  find_max_pix();
  /*
  Serial.print("My X: ");
  Serial.print(max_x);
  Serial.print("My Y: ");
  Serial.print(max_y);
  
  Serial.println("=================");
  */
}


/**

*/
bool setup_camera(framesize_t frameSize) {
  camera_config_t config;

  config.ledc_channel = LEDC_CHANNEL_0;
  config.ledc_timer = LEDC_TIMER_0;
  config.pin_d0 = Y2_GPIO_NUM;
  config.pin_d1 = Y3_GPIO_NUM;
  config.pin_d2 = Y4_GPIO_NUM;
  config.pin_d3 = Y5_GPIO_NUM;
  config.pin_d4 = Y6_GPIO_NUM;
  config.pin_d5 = Y7_GPIO_NUM;
  config.pin_d6 = Y8_GPIO_NUM;
  config.pin_d7 = Y9_GPIO_NUM;
  config.pin_xclk = XCLK_GPIO_NUM;
  config.pin_pclk = PCLK_GPIO_NUM;
  config.pin_vsync = VSYNC_GPIO_NUM;
  config.pin_href = HREF_GPIO_NUM;
  config.pin_sscb_sda = SIOD_GPIO_NUM;
  config.pin_sscb_scl = SIOC_GPIO_NUM;
  config.pin_pwdn = PWDN_GPIO_NUM;
  config.pin_reset = RESET_GPIO_NUM;
  config.xclk_freq_hz = 20000000;
  config.pixel_format = PIXFORMAT_GRAYSCALE;
  config.frame_size = frameSize;
  config.jpeg_quality = 12;
  config.fb_count = 1;

  bool ok = esp_camera_init(&config) == ESP_OK;

  // setup the camera 
  sensor_t *sensor = esp_camera_sensor_get();
  sensor->set_brightness(sensor, -2);     // -2 to 2
  sensor->set_contrast(sensor, 2);       // -2 to 2
  sensor->set_saturation(sensor, 0);     // -2 to 2
  sensor->set_special_effect(sensor, 2); // 0 to 6 (0 - No Effect, 1 - Negative, 2 - Grayscale, 3 - Red Tint, 4 - Green Tint, 5 - Blue Tint, 6 - Sepia)
  sensor->set_whitebal(sensor, 0);       // 0 = disable , 1 = enable
  sensor->set_awb_gain(sensor, 0);       // 0 = disable , 1 = enable
  sensor->set_wb_mode(sensor, 0);        // 0 to 4 - if awb_gain enabled (0 - Auto, 1 - Sunny, 2 - Cloudy, 3 - Office, 4 - Home)
  sensor->set_exposure_ctrl(sensor, 1);  // 0 = disable , 1 = enable
  sensor->set_aec2(sensor, 1);           // 0 = disable , 1 = enable
  sensor->set_ae_level(sensor, -1);       // -2 to 2
  sensor->set_aec_value(sensor, 300);    // 0 to 1200
  sensor->set_gain_ctrl(sensor, 1);      // 0 = disable , 1 = enable
  sensor->set_agc_gain(sensor, 0);       // 0 to 30
  sensor->set_gainceiling(sensor, (gainceiling_t)0);  // 0 to 6
  sensor->set_bpc(sensor, 0);            // 0 = disable , 1 = enable
  sensor->set_wpc(sensor, 1);            // 0 = disable , 1 = enable
  sensor->set_raw_gma(sensor, 1);        // 0 = disable , 1 = enable
  sensor->set_lenc(sensor, 1);           // 0 = disable , 1 = enable
  sensor->set_hmirror(sensor, 0);        // 0 = disable , 1 = enable
  sensor->set_vflip(sensor, 0);          // 0 = disable , 1 = enable
  sensor->set_dcw(sensor, 1);            // 0 = disable , 1 = enable
  sensor->set_colorbar(sensor, 0);       // 0 = disable , 1 = enable  
  sensor->set_framesize(sensor, frameSize);

  return ok;
}


/**
   Capture image and do down-sampling
*/
bool capture_still() {
  camera_fb_t *frame_buffer = esp_camera_fb_get();

  if (!frame_buffer)
    return false;

  // set all 0s in current frame
  for (int y = 0; y < H; y++)
    for (int x = 0; x < W; x++)
      current_frame[y][x] = 0;


  // down-sample image in blocks
  for (uint32_t i = 0; i < WIDTH * HEIGHT; i++) {
    const uint16_t x = i % WIDTH;
    const uint16_t y = floor(i / WIDTH);
    const uint8_t block_x = floor(x / BLOCK_SIZE);
    const uint8_t block_y = floor(y / BLOCK_SIZE);
    const uint8_t pixel = frame_buffer->buf[i];
    const uint16_t current = current_frame[block_y][block_x];

    // average pixels in block (accumulate)
    current_frame[block_y][block_x] += pixel;
  }

  // average pixels in block (rescale)
  for (int y = 0; y < H; y++)
    for (int x = 0; x < W; x++)
      current_frame[y][x] /= BLOCK_SIZE * BLOCK_SIZE;

#if DEBUG
  Serial.println("Current frame:");
  print_frame(current_frame);
  Serial.println("---------------");
#endif

  return true;
}

//  Different kernels:
// http://blog.dzl.dk/2019/06/08/compact-gaussian-interpolation-for-small-displays/
//Sigma=1
#define P0 (0.077847)
#define P1 (0.123317+0.077847)
#define P2 (0.195346+0.123317+0.123317+0.077847)
/*
  //Sigma=0.5
  #define P0 (0.024879)
  #define P1 (0.107973+0.024879)
  #define P2 (0.468592+0.107973+0.107973+0.024879)
*/
/*
  //Sigma=2
  #define P0 (0.102059)
  #define P1 (0.115349+0.102059)
  #define P2 (0.130371+0.115349+0.115349+0.102059)
*/



const float kernel[4][4] =
{
  {P0, P1, P1, P2},
  {P1, P0, P2, P1},
  {P1, P2, P0, P1},
  {P2, P1, P1, P0}
};


/*
   Convolve the image with a gaussian and find the maximum position of the laserbeam
   Inspired by: http://www.songho.ca/dsp/convolution/convolution.html
*/
bool convolve_gaussian() {
  // find center position of kernel (half of kernel size)
  int kCols = 4; // size kernel x
  int kRows = 4; // size kernel y
  int kCenterX = kCols / 2;
  int kCenterY = kRows / 2;

  for (int y = 0; y < H; y++)           // rows
  {
    for (int x = 0; x < W; x++)       // columns
    {
      proc_frame[y][x] = 0;   // Initiliaze with zero
      for (int m = 0; m < kRows; ++m)  // kernel rows
      {
        int mm = kRows - 1 - m;      // row index of flipped kernel
        for (int n = 0; n < kCols; ++n) // kernel columns
        {
          int nn = kCols - 1 - n;  // column index of flipped kernel

          // index of input signal, used for checking boundary
          int yy = y + (kCenterY - mm);
          int xx = x + (kCenterX - nn);

          // ignore input samples which are out of bound
          if ( yy >= 0 && yy < H && xx >= 0 && xx < W )
            proc_frame[y][x] += current_frame[yy][xx] * kernel[mm][nn];
        }
      }
    }
  }
#if 0 // DEBUG
  Serial.println("PRocessed frame:");
  print_frame(proc_frame);
  Serial.println("---------------");
#endif
}




/**
   Copy current frame to previous
*/
void find_max_pix() {
  int mymax = 0;
  
  for (int y = 0; y < H; y++) {
    for (int x = 0; x < W; x++) {
      if (proc_frame[y][x]>mymax){
        mymax = proc_frame[y][x];
        max_x = x;
        max_y = y;
      }
    }
  }
}

/**
   For serial debugging
   @param frame
*/
void print_frame(uint16_t frame[H][W]) {
  for (int y = 0; y < H; y++) {
    for (int x = 0; x < W; x++) {
      int myval = 0;
      if (frame[y][x] >0) myval = frame[y][x];
      Serial.print(myval);
      Serial.print(',');
    }

    Serial.println();
  }
}

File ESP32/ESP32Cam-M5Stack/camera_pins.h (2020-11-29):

#if defined(CAMERA_MODEL_WROVER_KIT)
#define PWDN_GPIO_NUM    -1
#define RESET_GPIO_NUM   -1
#define XCLK_GPIO_NUM    21
#define SIOD_GPIO_NUM    26
#define SIOC_GPIO_NUM    27

#define Y9_GPIO_NUM      35
#define Y8_GPIO_NUM      34
#define Y7_GPIO_NUM      39
#define Y6_GPIO_NUM      36
#define Y5_GPIO_NUM      19
#define Y4_GPIO_NUM      18
#define Y3_GPIO_NUM       5
#define Y2_GPIO_NUM       4
#define VSYNC_GPIO_NUM   25
#define HREF_GPIO_NUM    23
#define PCLK_GPIO_NUM    22

#elif defined(CAMERA_MODEL_ESP_EYE)
#define PWDN_GPIO_NUM    -1
#define RESET_GPIO_NUM   -1
#define XCLK_GPIO_NUM    4
#define SIOD_GPIO_NUM    18
#define SIOC_GPIO_NUM    23

#define Y9_GPIO_NUM      36
#define Y8_GPIO_NUM      37
#define Y7_GPIO_NUM      38
#define Y6_GPIO_NUM      39
#define Y5_GPIO_NUM      35
#define Y4_GPIO_NUM      14
#define Y3_GPIO_NUM      13
#define Y2_GPIO_NUM      34
#define VSYNC_GPIO_NUM   5
#define HREF_GPIO_NUM    27
#define PCLK_GPIO_NUM    25

#elif defined(CAMERA_MODEL_M5STACK_PSRAM)
#define PWDN_GPIO_NUM     -1
#define RESET_GPIO_NUM    15
#define XCLK_GPIO_NUM     27
#define SIOD_GPIO_NUM     25
#define SIOC_GPIO_NUM     23

#define Y9_GPIO_NUM       19
#define Y8_GPIO_NUM       36
#define Y7_GPIO_NUM       18
#define Y6_GPIO_NUM       39
#define Y5_GPIO_NUM        5
#define Y4_GPIO_NUM       34
#define Y3_GPIO_NUM       35
#define Y2_GPIO_NUM       32
#define VSYNC_GPIO_NUM    22
#define HREF_GPIO_NUM     26
#define PCLK_GPIO_NUM     21

#elif defined(CAMERA_MODEL_M5STACK_V2_PSRAM)
#define PWDN_GPIO_NUM     -1
#define RESET_GPIO_NUM    15
#define XCLK_GPIO_NUM     27
#define SIOD_GPIO_NUM     22
#define SIOC_GPIO_NUM     23

#define Y9_GPIO_NUM       19
#define Y8_GPIO_NUM       36
#define Y7_GPIO_NUM       18
#define Y6_GPIO_NUM       39
#define Y5_GPIO_NUM        5
#define Y4_GPIO_NUM       34
#define Y3_GPIO_NUM       35
#define Y2_GPIO_NUM       32
#define VSYNC_GPIO_NUM    25
#define HREF_GPIO_NUM     26
#define PCLK_GPIO_NUM     21

#elif defined(CAMERA_MODEL_M5STACK_WIDE)
#define PWDN_GPIO_NUM     -1
#define RESET_GPIO_NUM    15
#define XCLK_GPIO_NUM     27
#define SIOD_GPIO_NUM     22
#define SIOC_GPIO_NUM     23

#define Y9_GPIO_NUM       19
#define Y8_GPIO_NUM       36
#define Y7_GPIO_NUM       18
#define Y6_GPIO_NUM       39
#define Y5_GPIO_NUM        5
#define Y4_GPIO_NUM       34
#define Y3_GPIO_NUM       35
#define Y2_GPIO_NUM       32
#define VSYNC_GPIO_NUM    25
#define HREF_GPIO_NUM     26
#define PCLK_GPIO_NUM     21

#elif defined(CAMERA_MODEL_M5STACK_ESP32CAM)
#define PWDN_GPIO_NUM     -1
#define RESET_GPIO_NUM    15
#define XCLK_GPIO_NUM     27
#define SIOD_GPIO_NUM     25
#define SIOC_GPIO_NUM     23

#define Y9_GPIO_NUM       19
#define Y8_GPIO_NUM       36
#define Y7_GPIO_NUM       18
#define Y6_GPIO_NUM       39
#define Y5_GPIO_NUM        5
#define Y4_GPIO_NUM       34
#define Y3_GPIO_NUM       35
#define Y2_GPIO_NUM       17
#define VSYNC_GPIO_NUM    22
#define HREF_GPIO_NUM     26
#define PCLK_GPIO_NUM     21

#elif defined(CAMERA_MODEL_AI_THINKER)
#define PWDN_GPIO_NUM     32
#define RESET_GPIO_NUM    -1
#define XCLK_GPIO_NUM      0
#define SIOD_GPIO_NUM     26
#define SIOC_GPIO_NUM     27

#define Y9_GPIO_NUM       35
#define Y8_GPIO_NUM       34
#define Y7_GPIO_NUM       39
#define Y6_GPIO_NUM       36
#define Y5_GPIO_NUM       21
#define Y4_GPIO_NUM       19
#define Y3_GPIO_NUM       18
#define Y2_GPIO_NUM        5
#define VSYNC_GPIO_NUM    25
#define HREF_GPIO_NUM     23
#define PCLK_GPIO_NUM     22

#elif defined(CAMERA_MODEL_TTGO_T_JOURNAL)
#define PWDN_GPIO_NUM      0
#define RESET_GPIO_NUM    15
#define XCLK_GPIO_NUM     27
#define SIOD_GPIO_NUM     25
#define SIOC_GPIO_NUM     23

#define Y9_GPIO_NUM       19
#define Y8_GPIO_NUM       36
#define Y7_GPIO_NUM       18
#define Y6_GPIO_NUM       39
#define Y5_GPIO_NUM        5
#define Y4_GPIO_NUM       34
#define Y3_GPIO_NUM       35
#define Y2_GPIO_NUM       17
#define VSYNC_GPIO_NUM    22
#define HREF_GPIO_NUM     26
#define PCLK_GPIO_NUM     21

#else
#error "Camera model not selected"
#endif

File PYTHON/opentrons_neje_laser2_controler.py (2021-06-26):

# -*- coding: utf-8 -*-
"""
Created on Thu Apr  8 12:24:31 2021

@author: diederichbenedict
"""
import serial
import threading
import time

# TODO !!!
# https://github.com/anabolyc/neje-engraver-tool/blob/master/NejeEngraverApp/Form_Main.cs#L999
# Form_Main.SOFTWARE_TYPE.NOR
# Zoom = 1
MAX_WIDTH = 490
MAX_HEIGHT = 490
# PORT = "/dev/ttyUSB0"
# PORT = "COM4"


class pyGraver():
    def __init__(self, port="/dev/ttyUSB0"):
        self.remain_cmd = None
        self.cmd_todecode = None
        self.check_online = False
        self.askToStop = False
        self.uploadInProcess = False
        self.carvingPercentProgress = 100
        self.numericUpDown_times = 1
        self.fan_RPM = 0
        self.fan_Precent = 0
        self.serial = serial.Serial(port, 57600)
        self.location = [MAX_WIDTH//2, MAX_HEIGHT//2]
        if self.serial.isOpen():
            self.init_connexion()
        else:
            print("Error : no serial connection")

    def init_connexion(self):
        # #FF#09#5A#A5
        self.send_CMD(9, 90, 165)
        self.wait_data()
        # #FF#AA#08#01#01#5A#A5#55
        self.send_CMD_array([170, 8, 1, 1, 90, 165, 85])
        self.thread = threading.Thread(target=self.connect)
        self.thread.start()

    def connect(self):
        cont = True
        while cont:
            self.dataReceivedV2()
            time.sleep(0.02)
            if self.askToStop:
                cont = False

    def close(self):
        self.askToStop = True
        self.serial.close()

    def wait_data(self):
        finish = False
        while not finish:
            finish = self.dataReceived()
            time.sleep(0.02)
            
    def send_CMD(self, D1, D2, D3):
        buffer = bytes([255, D1, D2, D3])
        #print("send", buffer)
        self.serial.write(buffer)
        self.serial.flush()

    def send_CMD_array(self, arr):
        #print("send", arr)
        buffer = bytes([255]+arr)
        #print("send", buffer)
        self.serial.write(buffer)
        self.serial.flush()

    def decode(self, D1, D2, D3):
        # print(D1, D2, D3)
        if D1 == 0:
            print("ONLINE")
            self.online = True
            return
        # elif D1 == 1:
        #    break
        elif D1 == 2:
            print("CONNECTION OK !")

    def dataReceived(self):
        nbToRead = self.serial.inWaiting()
        if nbToRead == 0:
            return False
        #
        data = bytearray(self.serial.read(nbToRead))
        print("DATA:"+str(data))
        #
        if self.remain_cmd is not None:
            self.cmd_todecode = bytearray(self.remain_cmd)
            self.cmd_todecode.extend(data)
        else:
            self.cmd_todecode = bytearray(data)
        self.remain_cmd = None

        if (len(self.cmd_todecode) % 4 != 0):
            self.remain_cmd = bytearray(len(self.cmd_todecode) % 4)
            lr = len(self.remain_cmd)
            lt = len(self.cmd_todecode)
            for i in range(len(self.remain_cmd)):
                self.remain_cmd[i] = self.cmd_todecode[lt - lr + i]
            array2 = bytearray(self.cmd_todecode)
            self.cmd_todecode = bytearray(len(array2) - lr)
            for j in range(len(array2) - lr):
                self.cmd_todecode[j] = array2[j]
        cmd = self.cmd_todecode
        for k in range(len(cmd)):
            if (cmd[k] == 255) and (k+3) < len(cmd):
                self.decode(cmd[k + 1], cmd[k + 2], cmd[k + 3])
        return True

    def dataReceivedV2(self):
        if self.uploadInProcess:
            print("uploadInProcess")
            return False
        nbToRead = self.serial.inWaiting()
        if nbToRead == 0:
            return False
        data = bytearray(self.serial.read_until(b"\x55"))
        print("DATA:"+str(data))
        data = [data[i] for i in range(len(data))]
        
        if len(data) < 8:
            return
        if data[0] != 255 or data[1] != 170:
            return
        if data[2] == 8:
            self.readUploadInfo(data)
        elif data[2] == 11:
            self.readStatus(data)
        elif data[2] == 14:
            self.readCarvingProgress(data)
        elif data[2] == 16:
            self.readAfterUpload(data)
        else:
            print(data)

        print(data)
    def readAfterUpload(self, data):
        # receive after upload        --x--  --y--  --w--   --h--
        # [255, 170, 16, 2, 1, 1, 80, 0, 50, 0, 50, 0, 166, 0, 171, 85]
        if len(data) == 16 and data[:6] == [255, 170, 16, 2, 1, 1]:
            x = data[7]*256 + data[8]
            y = data[9]*256 + data[10]
            w = data[11]*256 + data[12]
            h = data[13]*256 + data[14]
            print("readAfterUpload", x, y, w, h)

    def readCarvingProgress(self, data):
        # carving progress          %  --x-- --y--
        # [255, 170, 14, 13, 2, 37, 0, 0, 1, 0, 65, 0, 0, 85]
        # [255, 170, 14, 13, 2, 37, 13, 0, 18, 0, 41, 0, 22, 85]

        if len(data) == 14 and data[:6] == [255, 170, 14, 13, 2, 37]:
            p = data[6]
            x = data[7]*256 + data[8]
            y = data[9]*256 + data[10]
            c = data[11]*256 + data[12]
            print("CarvingProgress", p, x, y, c)
            self.carvingPercentProgress = p

    def readUploadInfo(self, data):
        if data[:5] == [255, 170, 8, 4, 1]:
            if data[5] == 2:
                # [255, 170, 8, 4, 1, 2, 0, 85] # receive image info
                print("receive image info")
            elif data[5] == 3:
                if data[6] == 0:
                    # [255, 170, 8, 4, 1, 3, 0, 85] # waiting for image
                    self.waitingForImage = True
                else:
                    # [255, 170, 8, 4, 1, 3, 8, 85]  # upload en cours (%)
                    self.waitingForImage = False
                    print("Download image percent :", data[6])
            elif data[5] == 4:  # [255, 170, 8, 4, 1, 4, 1, 85] # upload fini
                print("Download image finished !")
                print(data)

    def readStatus(self, data):
        # statut
        # [255, 170, 11, 11, 2, 33, 255, 255, 255, 0, 85] 33 : temp
        if len(data) == 11 and data[:5] == [255, 170, 11, 11, 2]:
            temp = data[5]
            print("temperature :", temp)

    def moveXY(self, x, y):
        self.send_CMD_array([
            170, 16, 5, 1, 80, 1,
            int(x // 256), int(x % 256),
            int(y // 256), int(y % 256),
            0, 0, 0, 0, 85])

    def stopShowWindow(self):
        self.send_CMD_array([170, 16, 5, 1, 80, 0, 0, 0, 0, 0, 0, 0, 0, 0, 85])

    # laser power + idle (au repos ?)
    def setPWD(self, p, i):
        # TODO à tester !!
        # print("setPWD", p, i)
        self.send_CMD_array([170, 11, 3, 1, 15, p, i, 0, 0, 85])

    def stopCarving(self):
        print("stopCarving")
        self.send_CMD_array([170, 8, 2, 1, 1, 2, 85])
        # stop carving
        # FF#AA#08#02#01#01#02#55
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

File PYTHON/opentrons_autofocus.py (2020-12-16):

# -*- coding: utf-8 -*-
"""
Created on Wed May 27 13:46:54 2020

@author: diederichbenedict
"""
from scipy.ndimage import  gaussian_filter
import tifffile as tif
import cv2 
import numpy as np
import matplotlib.pyplot as plt
import matplotlib as mpl
import matplotlib  
from scipy.optimize import curve_fit
import serial
import time
import time, datetime, os
import xystepper as xy
import picamera
import numpy
import cv2


## TESTING autofocus 
import serial

# connect to the focussensor
focussensor = "/dev/cu.SLAB_USBtoUART"
ser = serial.Serial(focussensor, 115200, bytesize=8, stopbits=serial.STOPBITS_ONE, parity=serial.PARITY_NONE)
ser.flushInput()



# GLOBAL PARAMETERS
myfolder = './RESULTS/'

# Connect GLBR to Raspi: https://github.com/grbl/grbl/issues/1316

# Initialize the USB-Serial connection
serial = serial.Serial("/dev/ttyUSB0",115200)
time.sleep(1) # connect to ARduino

# Wake up grbl
serial.write("\r\n\r\n".encode())

# initiliaze camera
cam = picamera.PiCamera()

Npix_x, Npix_y = 640, 320 # (3280, 2464)
cam.resolution = (Npix_x, Npix_y)
cam.awb_mode = 'off'
cam.iso = 800
cam.start_preview()
#cam.exposure_compensation = 8
# Camera warm-up time
time.sleep(3)
print(cam.exposure_speed)

print(cam.framerate)
#cam.exposure_mode = 'off'
from fractions import Fraction
cam.framerate = Fraction(5,1)
cam.shutter_speed = 100000

# parameters for the x/y stage 
stepsize_x = 0.03 # One STEPSIZE in X/Y of the cheap-stage  is 17.27 µm
stepsize_y = 0.023 # One STEPSIZE in X/Y of the cheap-stage  is 17.27 µm
myoffsetx = 0  # offset steps for the x dirrection
myoffsety = 0 # offset steps for the y dirrection
mybacklashx = 7
mybacklashy = 45 # this is required to offset the stage from the non-moving rim
Nx = 2
Ny = 2
stepsizeZ = 5 # 10
z_min = 500
z_max = 700



# Initialize position of the XY-stages
Stepper_XY = xy.xyStepper(myserial=serial, mycurrentposition=(0,0), mystepper='xy', backlash=mybacklashx)

iscan = 0
try:
    # move stepper forward/backward in X
    for ix in range(Nx):
        for iy in range(Ny):
            #print('going to position X/Y :' + str(ix)+'/'+str(iy))
            # go to xy-step
            stepx = stepsize_x*ix+myoffsetx
            stepy = stepsize_y*iy+myoffsety
            
            Stepper_XY.go_to(stepx, stepy)
            time.sleep(.5)
            # grab a frame and wait until the camera settles
            # print('Grabbing frame')
            mystdall = []
            myzstepsall = []
            #background = np.empty((Npix_y, Npix_x, 3), dtype=np.uint8)
            #cam.capture(background, 'bgr')
                
            for iz in range(z_min,z_max,stepsizeZ):
                Stepper_XY.go_to_z(iz)
                time.sleep(0.)
                image = np.empty((Npix_y, Npix_x, 3), dtype=np.uint8)
                cam.capture(image, 'bgr')
                #image = np.mean(image,-1)
                #image = image/(background+1)
                image = image[:,:,1]
                image = gaussian_filter(image, 1.5)
                #image = image-np.min(image)
                #image = image/np.max(image)*255
                mystd = np.std(image)
                #cv2.imwrite(filename, image)
                mystdall.append(mystd)
                myzstepsall.append(iz)
                
                print(str(iscan)+ " STDV: " + str(mystd))
            #Stepper_XY.go_to_z(0)     
    # Reset position of X/Y stepper
            # fitting 
            mystd = np.squeeze(np.array(mystdall))
            myallz = np.squeeze(np.array(myzstepsall))

            mystd -= np.min(mystd)
            mystd /= np.max(mystd)
            mystd = gaussian_filter(mystd,2)

            def gauss(x, a0, mu, sigma):
                return a0*np.exp(-(x-mu)**2/(2.*sigma**2))

            xdatafit = np.linspace(0,1,100) #mystd.shape[0])
            xdata = np.linspace(0,1,mystd.shape[0])
            p0 = [1., np.mean(mystd), 2.]
            coeff, var_matrix = curve_fit(gauss, xdata, mystd, p0=p0)
            
            # Get the fitted curve
            gauss_fit = gauss(xdatafit, coeff[0], coeff[1], coeff[2])
            gaussmax = coeff[1] # np.argmax(gauss_fit)
            print(gaussmax)
            zstepmax = np.int32(np.squeeze(gaussmax*(z_max-z_min)+z_min))
            #zstepmax = np.squeeze(myallz[gauss_fit==np.max(gauss_fit)])
            #zstepmax = np.squeeze(myallz[mystd==np.max(mystd)])
            print("Going to: "+str(zstepmax))
            # go to position with max stdv
            Stepper_XY.go_to_z(zstepmax + stepsizeZ)
            time.sleep(1)

            filename = myfolder+'/scan_xyz_'+str(iscan) + '_' + str(stepx)+'_'+str(stepy)+'_'+str(iz)+'.jpg'
            cam.capture(filename)
            iscan +=1



except Exception as e: 
    print(e)
    cam.stop_preview()
    Stepper_XY.go_to_z(0)
    Stepper_XY.go_to(myoffsetx, myoffsety)


cam.stop_preview()
plt.plot(xdata, mystd, label='raw data')
plt.plot(xdatafit, gauss_fit, label='Fitted ydata')
plt.show()

Stepper_XY.go_to_z(0)

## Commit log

2020-11-13 Updating Documentation
    [01_Autofocus_Magnet_holder_v0.0002.ipt, 01_Autofocus_Magnet_holder_v0.0003.ipt, 01_Autofocus_Magnet_holder_v0.ipt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]
2020-11-17 Updated Documentation and added Spectra of RGB LED
    [00_3rdleg.stl]
2020-11-17 Added some results from the fluorescence setup.
    [00_3rdleg.ipt, 01_Slide_camera_x_v0.0002.ipt, 01_Slide_camera_x_v0.0005.ipt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]
2020-11-20 Udpated mechanical assembly
    [02_Opentrons_Microscope_Base_v0.0002.ipt, 02_Opentrons_Microscope_Base_v0.0006.ipt, 02_Opentrons_Microscope_Base_v0.0007.ipt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]
2020-11-22 Updated Solenoid-based z-focus
    [00_COMAR_Mirror_10mm.ipt, 00_JF-0530B-solenoid.0001.ipt, 00_JF-0530B-solenoid.ipt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]
2020-11-29 Adding software-based autofocus for solenoid; Adding reflection-based autofocus using ESP32Camera
    [00_3rdleg.0001.ipt, 00_3rdleg.ipt, 00_Z_Focus_CCTV_Camera.ipt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]
2020-12-03 Adding rudimentary find-focus from camera position to the esp32
    [00_Beampath_Autofocus.0005.ipt, 00_Beampath_Autofocus.ipt, 00_ESP32_CAM.0004.ipt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]
2020-12-21 Adding Stay-in-focus mechanism using the ESP32 camera
    [00_Beampath_Autofocus _2.0008.ipt, 00_Beampath_Autofocus _2.ipt, 00_ESP32_Camera_only.ipt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]
2021-01-10 Updated Z-stage
    [08_Opentrons_Autofocus_flexurebaering.0007.ipt, 08_Opentrons_Autofocus_flexurebaering.0009.ipt, 08_Opentrons_Autofocus_flexurebaering.ipt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]
2021-01-27 Cleaning up the INVENTOR Stuff; Testing with autofocus for the ESP32, but didn't have much success.
    [00_3rdleg.0001.ipt, 00_3rdleg.ipt, 00_Beampath_Autofocus _2.0008.ipt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]
2021-03-06 Updated to latest mechanical design
    [00_LED_neopixel_single.0002.ipt, 00_LED_neopixel_single.ipt, 00_MGN12H, LINEAR GUIDE BLOCK.0002.ipt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]
2021-03-16 Further udpates on the documentation
    [00_3rdleg.stl, 00_gear_nema.0004.ipt, 00_gear_nema.ipt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]
2021-03-16 Cleaning up!
    [Opentrons_FocusSensorMeasure.xlsx, Opentrons_MeasureZovertime.xlsx, Opentrons_MeasureZovertime_compression_picamera.xlsx]
2021-03-26 Update with Opentrons Protocol and Sample files;
    [00_Raspberry_Pi_3.iam, 04_OPENTRONS_Microscope_wellplate_base.0016.ipt, 04_OPENTRONS_Microscope_wellplate_base.0017.ipt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]
